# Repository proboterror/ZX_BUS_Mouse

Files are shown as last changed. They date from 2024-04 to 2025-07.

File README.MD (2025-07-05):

# ZX-BUS PS/2 Kempston Mouse Controller

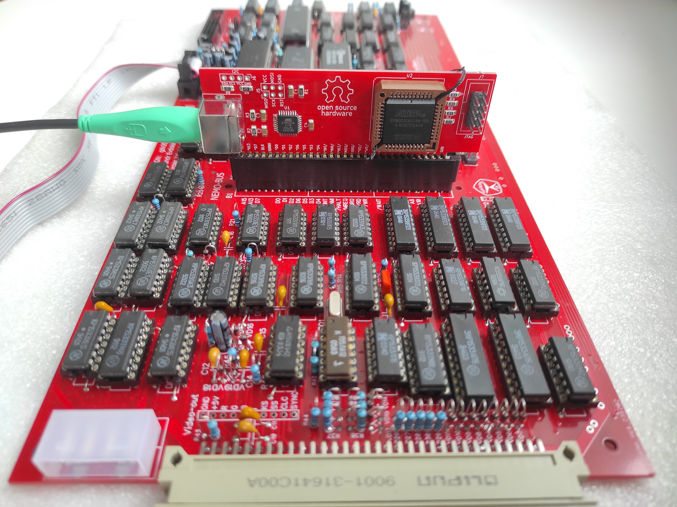
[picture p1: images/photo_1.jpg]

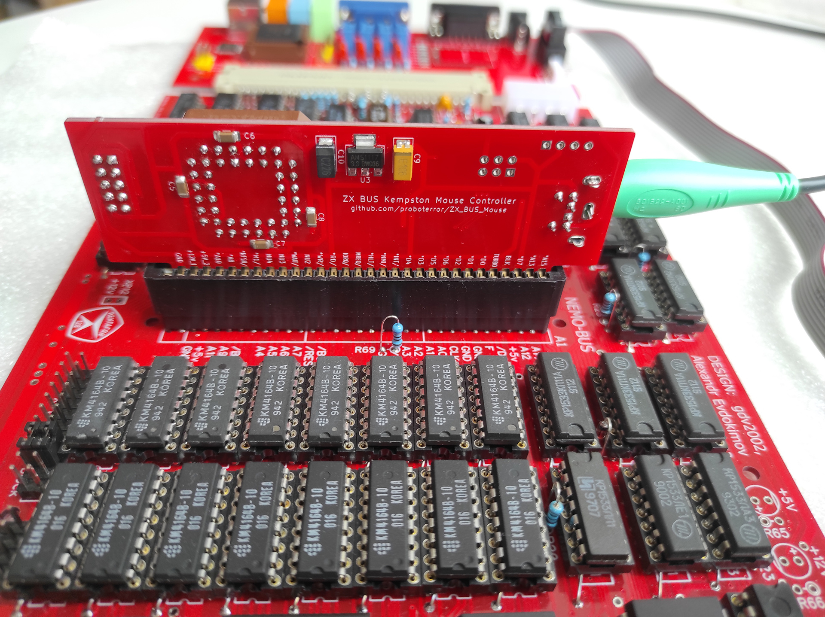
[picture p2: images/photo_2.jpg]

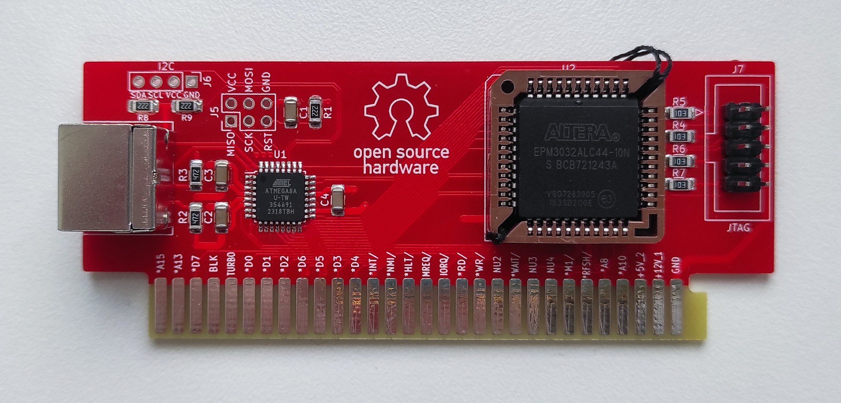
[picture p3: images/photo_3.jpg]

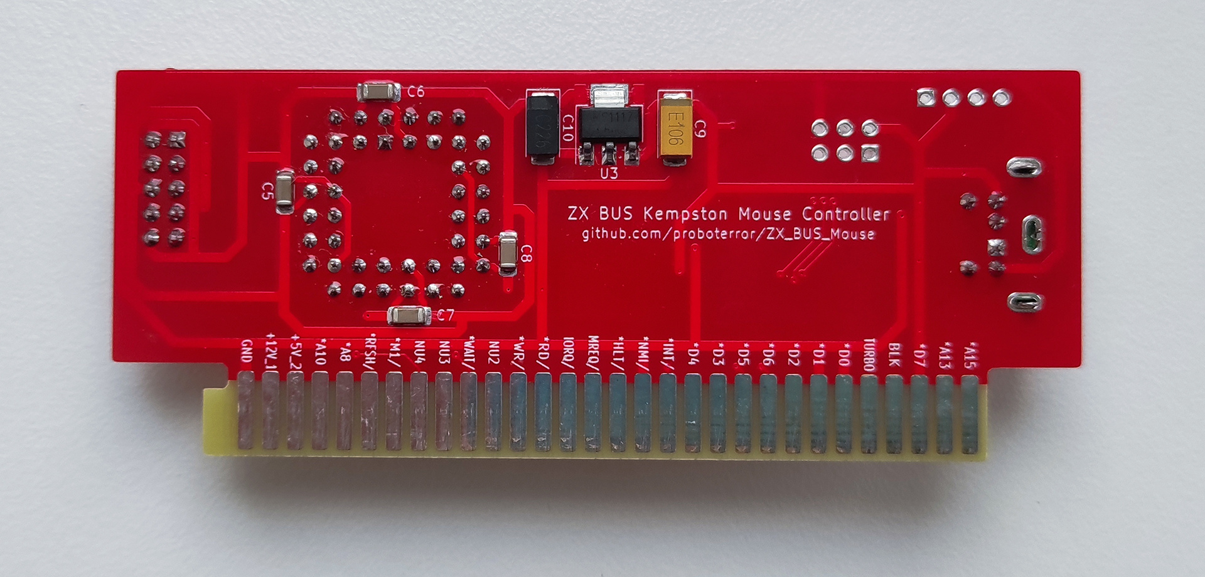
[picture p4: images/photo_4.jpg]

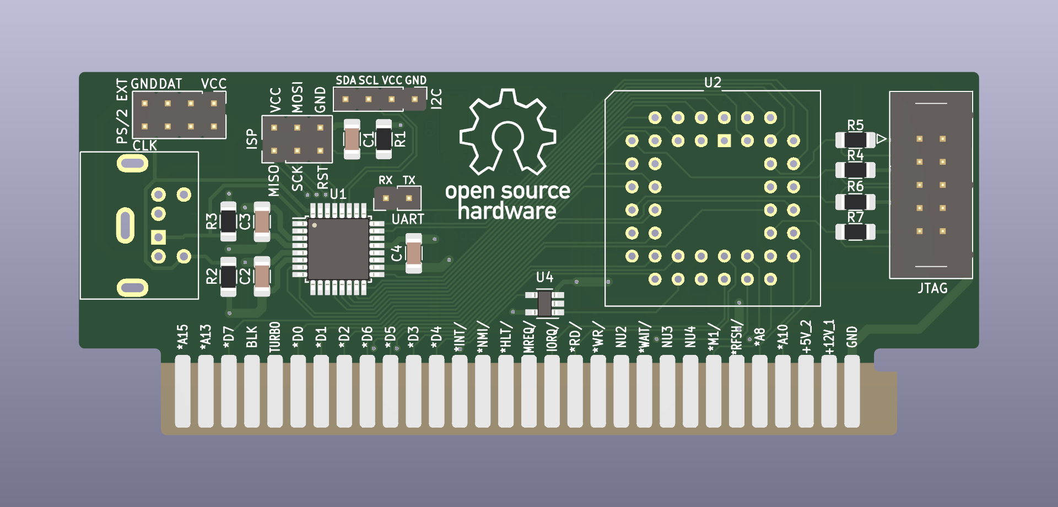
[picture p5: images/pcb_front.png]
pcb_front

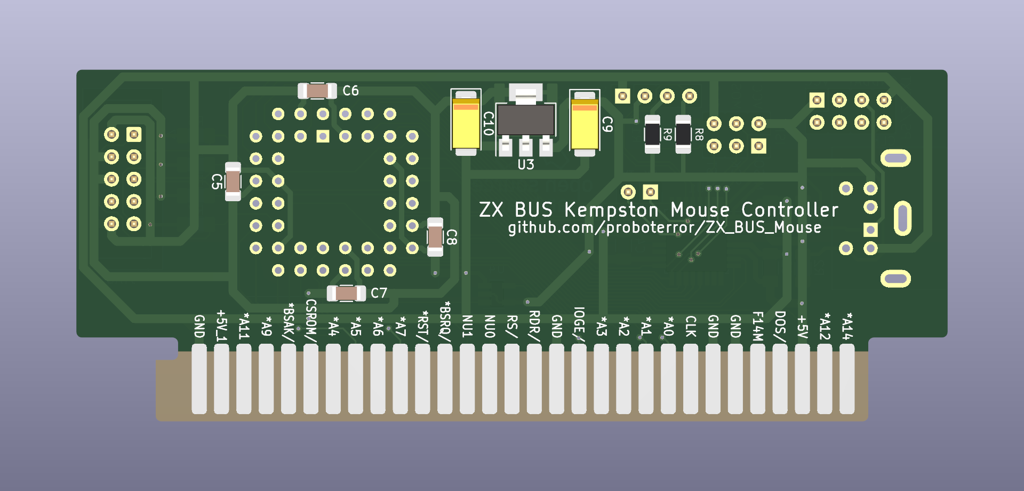
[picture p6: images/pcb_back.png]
pcb_back

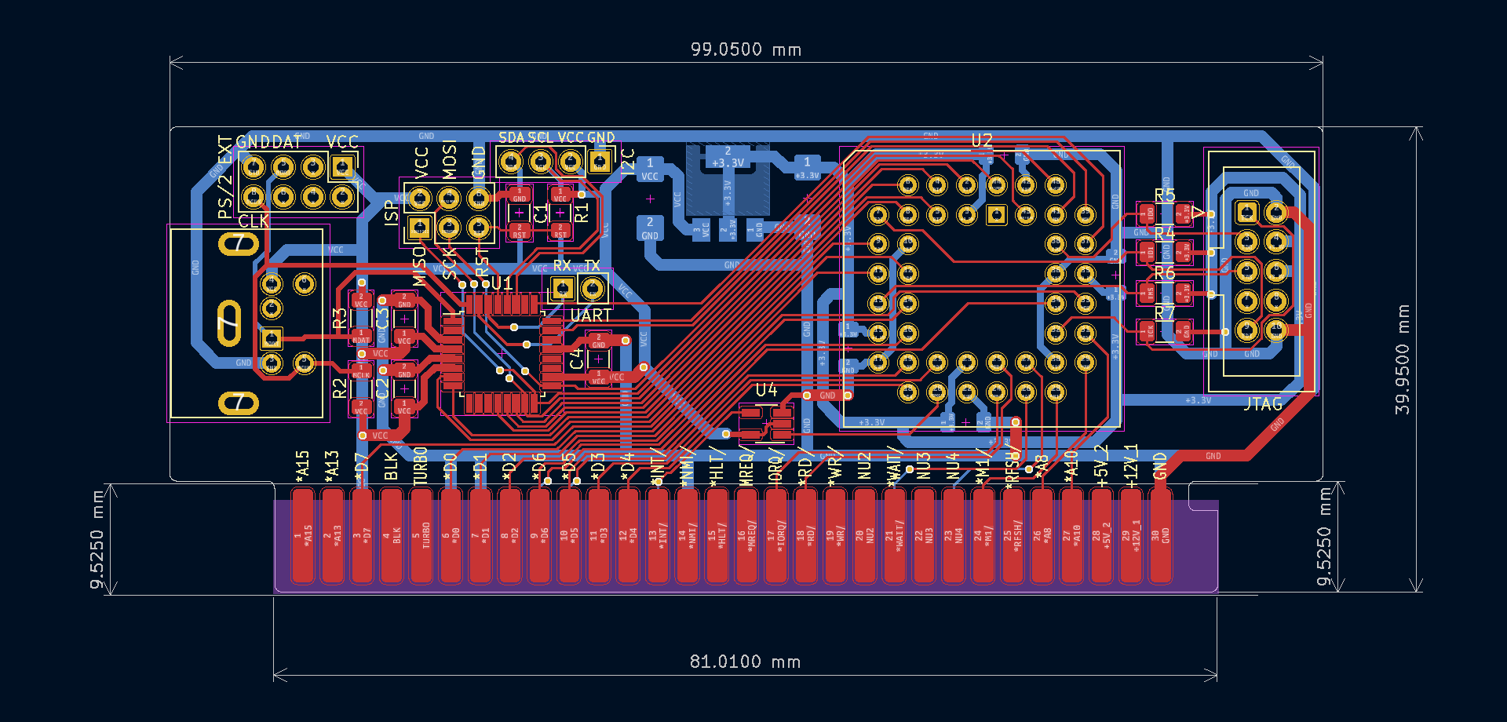
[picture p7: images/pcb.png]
pcb

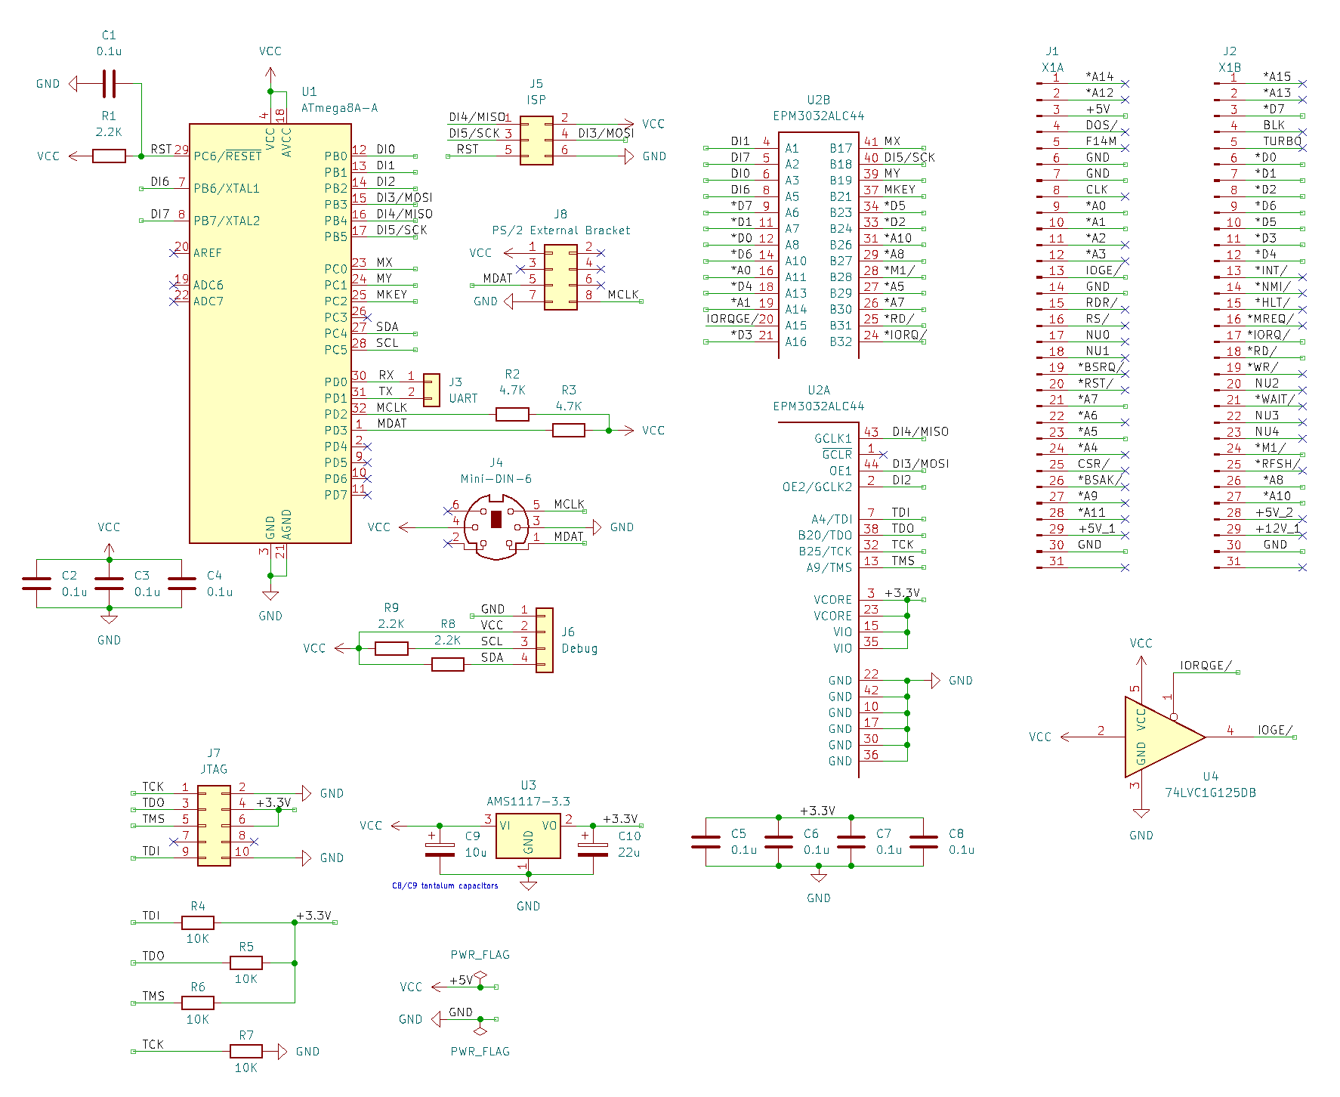
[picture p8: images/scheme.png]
scheme


## История версий
**V.1.0**
* Сигнал IORQGE/ имеет уровень 3.3V (LVTTL). Плата не работает корректно в ZX-BUS XTRaiser.
* Для включения поддержки колеса мыши нужна CPLD EPM3064.
* При включении регистры контроллера MX, MY, MKEY инициализируются некорректно в 0xFF, 0x80, 0x60: должно быть 0x80, 0x60, 0xFF (в регистре MKEY кнопки должны быть отжаты).

**V.1.1**
* Сигнал IORQGE/ буферизирован через 3-state buffer 74LVC1G125 до уровня TTL (5V) для исправления конфликта с ZX-BUS XTRaiser, общей стабильности и предупреждения обратного тока с других карт через IO выход CPLD. Решение подсмотрено в схемах в ZX-Multisound и ZXM-GeneralSound.
* Добавлен разъем для подключения внешнего брекета PS/2 (распространенная распиновка PC AT 486/Pentium материнских плат)
* Добавлен разъем UART для отладки
* Ширина краевого разъема ZX-BUS увеличена с 80 до 81 мм
* Описание схемы в CPLD переписано на Verilog и оптимизировано для поддержки колеса мыши на EPM3032 при отказе от третьей кнопки мыши (32 macrocells). Возможна сборка без поддержки колеса мыши (31 macrocells) и с полной поддержкой (34 macrocells).
* Не корректно работает с теневым монитором Scorpion (меню, не грузятся программы из ROM диска при активированной мыши). Нужен сигнал A15 в дешифрацию портов.

**V.1.2**
* Исправление загрузки с ROM диска в ПрофПЗУ Scorpion ZS 256. В дешифрацию портов и формирование сигнала IORQGE добавлен сигнал A15.

## Входные требования:
* Разработать максимально компактный простой в повторении интерфейс PS/2 Kempston Mouse для шины ZX BUS.
* Исходники прошивок микроконтролллеров / CPLD, схема и разводка платы должны быть полностью открыты.
* Сигнал WAIT микропроцессора не должен использоваться.

Не входит в требования:
* Поддержка USB мыши. Объем аппаратной и программной поддержки USB стека в микроконтроллере не соответствует сложности задачи.

## Описание интерфейса Kempston Mouse
Контроллер доступен как 3 8-разрядных регистра кнопок и осей X/Y MKEY, MX, MY по следующим адресам портов:
<pre>
#FADF 1111 1010 1101 1111 BUTTONS
#FBDF 1111 1011 1101 1111 MX
#FFDF 1111 1111 1101 1111 MY
</pre>

* Биты 0-2 регистра MKEY соответствуют инвертированным значениям левой, правой, средней кнопок мыши.<br>
* Бит 3 регистра MKEY зарезервирован под четвертую кнопку мыши и всегда равен 1.<br>
* Биты 4-7 регистра MKEY хранят значение оси mouse wheel, если она поддержана (начальное значение %0000). Если ось mouse wheel не поддержана, всегда содержат %1111.

При переполнении 8-bit значений координат осей происходит перенос значения. Фактически значения осей 8-бит целое со знаком в дополнительном коде.

Спецификация оси mouse wheel была публично зафиксирована в [сообщении в Fido эхоконференции REAL SPECCY](https://groups.google.com/g/fido7.real.speccy/c/Qeid4aFhjRg)

Дополнительная информация: [https://speccy.info/Kempston_Mouse](https://speccy.info/Kempston_Mouse)

## Некоторые исторические реализации и публикации
[Original Kempston Mouse Interface (1986)](https://k1.spdns.de/Vintage/Sinclair/82/Peripherals/Mouse%20Interfaces/Kempston%20Mouse%20Interface/)

[ZX-Ревю 1995 #1](history/zx-review_1995-01.txt)
[[схема]](history/zx-review_1995-01.png)<br>
KEMPSTON-MOUSE<br>
(С) М.Свечков (схема), К.Мехедов (программа) 1995

Фирма Scorpion & Д.К. (Санкт-Петербург 1995-97)<br>
[Контроллер IBM PC-клавиатуры и мыши](https://web.archive.org/web/20010308054936/http://scorpion.ru/spectrum/hard/kontroller_IBM.htm)<br>
[Схема](history/scorpion_keyboard_mouse_controller_scheme.png) [Прошивка V2.5](history/scorpion_keyboard_mouse_controller_2.5_firmware.zip)<br>
Инструкция по работе и подключению: V2.1: [1](history/scorpion_keyboard_mouse_controller_2.1_1.png) [2](history/scorpion_keyboard_mouse_controller_2.1_2.png) 
V2.5: [1](history/scorpion_keyboard_mouse_controller_2.5_1.jpg) [2](history/scorpion_keyboard_mouse_controller_2.5_2.jpg)<br>
Публикации:
[ZX Format #01 (31 октября 1995)](https://zxpress.ru/article.php?id=319)
[On-Line #15 (17 декабря 1995)](https://zxpress.ru/article.php?id=1989)
[On-Line #16 (24 декабря 1995)](https://zxpress.ru/article.php?id=1994)

[Схема от Михаила Кондратьева (17 апреля 1995)](history/kempmous.txt)

Интерфейс Kempston Mouse от Create Soft (Максим Романов, Mad Max & RML) (Санкт-Петербург)<br>
[ZX-Format #5 (12 декабря 1996)](https://zxdn.narod.ru/hardware/zf5kempm.htm)
[[screenshot]](history/zx-format_5.png)<br>
Схемa KEMPSTON MOUSE<br>
(С) Mad Max

[Spectrofon #20 (12 октября 1996)](https://zxpress.ru/article.php?id=4708)
[[text]](history/spectrofon_20.txt)
[[screenshot]](history/spectrofon_20.png)
[[схема]](history/spectrofon_20_kempston_mouse.png)<br>
ZX-SPECTRUM и МЫШЬ<br>
(C) Владимиp Лаpьков, 1996, Санкт-Петербург

AY Mouse<br>
[ZX Power #1 (12.10.1996)](https://zxdn.narod.ru/hardware/zpw1ayms.htm)<br>
В ЗАЩИТУ БЕДНОЙ МЫШКИ<br>
(C) V.M.G., Харьков

[Optron #13 (12 июня 1998)](https://zxdn.narod.ru/hardware/op13kemp.htm)
[[screenshot]](history/optron_13.png)<br>
Kempston mouse<br>
(C) Рашпиль, Сергей Филимонов

[ZX Club #09 (31 октября 1998)](https://zxpress.ru/article.php?id=14937)
[[screenshot]](history/zx-club_9.png)<br>
Kempston mouse<br>
(С) SERGIUS PUZZLER / PROXIMA

[Adventurer #11 (31 июля 2000)](https://zxdn.narod.ru/hardware/ad11kmse.htm)
[[screenshot]](history/adventurer_11.png)<br>
Описание на подключение Kempston MOUSE (простая и маленькая схема)<br>
(C) Паршуков XN0ByS Юрий/CPU

[Deja Vu #0A (30 сентября 2000)](https://zxdn.narod.ru/hardware/dv0akemp.htm)
[[text]](https://zxpress.ru/article.php?id=11221)
[[screenshot]](history/dejavu_0a.png)<br>
Схема Kempston Mouse Interface (v2.1) на БИС KP580BB55A<br>
(C) Felix Knajzev

Поддержка оси mouse wheel<br>
[DonNews #19 (26 февраля 2003)](https://zxpress.ru/article.php?id=6538)
[[screenshot]](history/donnews_19.png)<br>
KEMPSTON MOUSE INTERFACE<br>
(C) Bit/XXL

[Схема контроллера мыши на AT89C2051 (MSC-51)](history/kmsps2.txt)<br>
Опубликовано в ZX-Net эхоконференции HARDWARE.ZX (21 Aug 2000)<br>
(C) Eugene Stahov 1999-2000<br>
Микроконтроллер AT89C1051/AT89C2051, исходный код прошивки закрыт.<br>
Использует сигнал WAIT при опросе регистров интерфейса.

[PS/2 -> Kempston Mouse Adapter v2.0](history/atmelps2.txt)<br>
Опубликовано в Fido эхоконференции ZX.SPECTRUM (2003-01-10)<br>
(C) 1999-2000 Studio STALL (Eugene Stahov)<br>
(C) 2003 Kamil Karimov<br>
Микроконтроллер AT90S2313 (или AT90S1200), исходный код прошивки закрыт.<br>
Использует сигнал WAIT при опросе регистров интерфейса.

[PS/2 -> Kempston Mouse Adapter v4.0](history/zxkmv40.zip)
[[схема]](history/zxkm4.png)<br>
(C)2010 Kamil Karimov<br>
Не использует сигнал WAIT.<br>
Для обеспечения работы контроллера без торможения Z80 микроконтроллер ATTiny2313 работает на частоте 20 Мгц.<br>
Исходный код прошивки микроконтроллера закрыт.

The Kempston Mouse Turbo Interface [2006/2008](https://velesoft.speccy.cz/kmturbo-cz.htm)/[2011](https://velesoft.speccy.cz/kmouse/km-doc/kempston_mouse_turbo_interface/km-t_2011/k-mouse2011-doc.pdf) by Velesoft and Ben Versteeg<br>
[PC Mouse and Kempston joystick Interface for the Sinclair ZX Spectrum](https://www.benophetinternet.nl/hobby/kmt/)<br>
Поддержка master/slave mouse, mouse wheel.<br>
Микроконтроллер PIC16F84A + CPLD XC9572X<br>
Исходный код прошивки микроконтроллера закрыт.

[Z-Controller](http://pentagon.nedopc.com/info.htm)<br>
(C) Алексей Жабин KingOfEvil 2007<br>
Позволяет подключать к ZX Spectrum стандартную клавиатуру и мышь с интерфейсом PS/2, IDE-устройства, карты флеш-памяти стандарта SD. Устройство предназначено для установки в слот ZX Bus.<br>
[Документация](http://svn.zxevo.ru/filedetails.php?repname=pentevo&path=/docs/ZC.pdf)<br>
Микроконтроллер КР1878ВЕ1 + CPLD EPM7128SLC84<br>
[Исходный код прошивок CPLD и микроконтроллера открыт в 2024 году](https://github.com/koe1234/Z-controller)

[ZX Evolution](http://www.nedopc.com/zxevo/zxevo.php)<br>
(C) NedoPC 2010<br>
Периферийный контроллер ATMEGA128<br>
PS/2 интерфейс клавиатуры и мыши<br>
[Open source](http://svn.zxevo.ru/listing.php?repname=pentevo)

[ZX_Multi_Card ZXMC1/ZXMC2](https://zx-pk.ru/threads/609-zx_multi_card.html)<br>
(C) caro Kamil Karimov 2005<br>
Поддерживает:<br>
- IBM AT клавиатуру - эмулирует стандартную клавиатуру Спектрума;<br>
- PS/2 мышка - эмулирует Кемпстон мышку (с колесом);<br>
- RS232 - поддержка внешнего модема с адресацией по Кондратьеву.<br>
- Часы реального времени (RTC)

Closed source

[Схема контроллера Kempston Mouse для Nemo-BUS](https://zxbyte.ru/kempston_mouse_for_zx.htm) (модификация схемы из Spectrofon #20)<br>
(C) Prusak 2016

[Контроллер для USB клавиатуры и мыши](https://zx-pk.ru/threads/34912-kontroller-dlya-usb-klaviatury-i-myshi.html)
[[github]](https://github.com/Igor-azx987sa/ZXKM)<br>
(С) Игорь Матвеев @azx987sa 2023<br>
Микроконтроллер CH9350<br>
Closed source

## Детали реализации:
Для реализации была выбрана связка ATmega8 + EPM3032.<br>
Общая идея контроллера Kempston Mouse на ATmega+EPM3032, [схема включения и выбор битов адреса для дешифрации портов](images/deltagon_1.5_mouse_controller.png) были взяты из [Deltagon 1.5](https://t.me/Pentagon_ZX_Chat/126403) (C) Евгений Королёв @djking26, Игорь Матвеев @azx987sa.

Прошивка ATmega для обработки протокола написана на языке C. В отдельной ветке есть упрощенная прошивка на библиотеках Arduino.<br>
Аппаратные прерывания ATmega по фронтам сигналов PS/2 MDATA/MCLK и таймеры не использовались для большей понятности кода. Тем не менее, сигналы MDATA/MCLK подключены к входам INT1/INT0 микроконтроллера, есть [альтернативная прошивка](https://github.com/proboterror/ZX_BUS_Mouse/tree/interrupt_processing), использующая аппаратное прерывание от сигнала PS/2 clock. Альтернативная прошивка предназначена в первую очередь для разработчиков.

Реализация регистров интерфейса, схемы дешифрации адресов и формирования сигнала IORQGE для CPLD EPM3032 выполнена на языке Verilog. Также есть признанная менее понятной реализация на VHDL.

Текущая реализация использует 31 из 32 macrocells в CPLD EPM3032 c отключенными битами оси mouse wheel в регистре кнопок мыши, 33 macrocells при включении битов оси mouse wheel.<br>
Теретически возможно использование менее доступной и более дорогой CPLD EPM3064 или оптимизация модели в Verilog и распределения ресурсов в CPLD.<br>
По умолчанию включена поддержка двух кнопок и mouse wheel, используется 32 macrocells.

При подаче питания на контроллер до прихода первого пакета событий от PS/2 мыши в регистры MKEY, MX, MY всегда записываются значения 0xFF, 0x80, 0x60.<br>
При отключенной поддержке оси mouse wheel в старших 4 битах регистра MKEY %1111, при включенной поддержке начальное значение оси %0000.

Формирование сигнала IORQGE/ происходит исходя из общих битов адресов портов A0,A1,A7,A5/ и сигнала M1/.

Отладка устройства проводилась на [Pentagon 2024](https://t.me/Pentagon_ZX_Chat/125656) и сверялась с эмулятором Unreal Speccy 0.39.0, выбранным как референс реализации.
Подтверждена работа на Scorpion ZS 256, Scorpion ZS 1024, Pentagon 1024ZP Crocodile Edition.

Условная эквивалентная схема контролллера в CPLD:
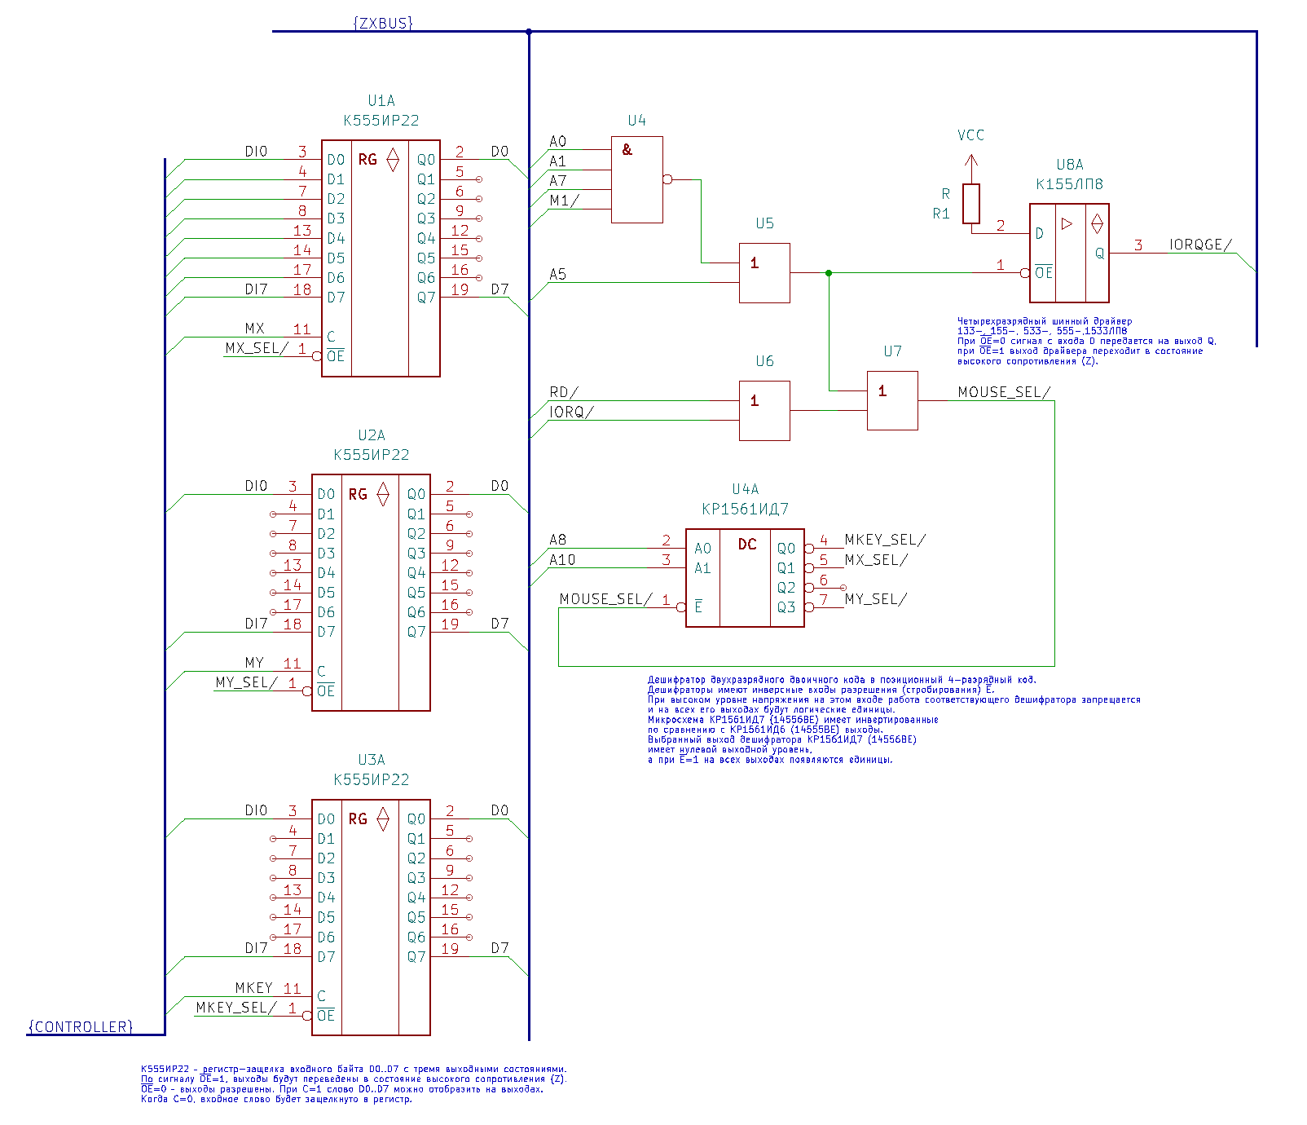
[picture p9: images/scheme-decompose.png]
scheme-decompose


## Известные проблемы:
На Scorpion ZS 256 в меню сервисного монитора мышь работает некорректно, при этом тест, загруженный в RAM, работает корректно.
Не работает загрузка с ROM диска в ПрофПЗУ при включенной опции графических манипуляторов.
Симптоматически исправилось включением сигнала A15 в схему дешифрации, аргументированного объяснения этому пока нет. Также проблема исправляется использованием сигнала /DOS.

Была замечена некорректная работа регистров осей в CPLD: выглядело как перепутанная пара битов. Решилось перекомпиляцией описания схемы и прошивкой CPLD.

На некоторых платах с неправильной реализацией IORQGE теоретически возможен конфликт с портом Kempston Joystick.

## Сомнительно:
PS/2 мышь может требовать задержку перед инициализацией после подачи питания. Решено перезагрузкой контроллера после 2 секунд ожидания инициализации устройства PS/2.

Gluk Reset Service проверяет наличие мыши сразу после включения (24 ms для Pentagon 2024: 10K+10uF в цепи сброса Z80: длительность RESET 10 ms).<br>
Проверки:<br>
- В цикле неясной длительности проверяется, что значение оси X не меняется
- Проверяется, что регистр KEY не равен регистру X
- Проверяется, что младшие 3 бита регистра KEY равны 1

Проблема:<br>
Мышь при включении автоматически не определяется, но определяется после сброса. Можно принудительно включить мышь через клавишу [8].<br>
Суть проблемы в том, что микроконтроллер ATmega не успевает проинициализировать PS/2 мышь (1-2 s) и выставить значения регистров контроллера по умолчанию (~6 us).<br>

Варианты решения:<br>
- Для определения наличия подсоединенной к контроллеру мыши требуется до 1-2 секунд, в течении которых сигнал /RESET Z80 удерживается контроллером, как это например сделано в контроллере ZXMC.
- Инициализировать регистры контроллера сразу после включения, не дожидаясь проверки наличия PS/2 мыши. Все еще может требовать внешней задержки старта Z80. Для ПО подобного Gluk тест наличия мыши будет проходить, даже если PS/2 мышь не присоединена.

В коде реализован второй вариант.

## Bill of materials
|Ref|Qnty|Value|Cmp name|Footprint|Description|
|-----|-----|-----|-----|-----|-----|
|C1, C2, C3, C4, C5, C6, C7, C8|8|0.1u|C|Capacitor_SMD:C_1206_3216Metric|Unpolarized capacitor|
|C9|1|10u|C_Polarized|Capacitor_Tantalum_SMD:CP_EIA-6032-28_Kemet-C_Pad2.25x2.35mm|Polarized capacitor|
|C10|1|22u|C_Polarized|Capacitor_Tantalum_SMD:CP_EIA-6032-28_Kemet-C_Pad2.25x2.35mm|Polarized capacitor|
|J4|1|Mini-DIN-6|Mini-DIN-6|Connector_Mini-DIN_Female_6Pin_2rows|6-pin Mini-DIN connector|
|J5|1|Conn_02x03_Odd_Even ISP|Conn_02x03_Odd_Even|Connector_PinHeader_2x03_P2.54mm_Vertical||
|J7|1|Conn_02x05_Odd_Even JTAG|Conn_02x05_Odd_Even|Connector_IDC-Header_2x05_P2.54mm_Vertical||
|R1|1|2.2K|R|Resistor_SMD:R_1206_3216Metric|Resistor|
|R2, R3|2|4.7K|R|Resistor_SMD:R_1206_3216Metric|Resistor|
|R4, R5, R6, R7|4|10K|R|Resistor_SMD:R_1206_3216Metric|Resistor|
|U1|1|ATmega8A-U|ATmega8A-U|Package_QFP:TQFP-32_7x7mm_P0.8mm|16MHz, 8kB Flash, 1kB SRAM, 512B EEPROM, TQFP-32|
|U2|1|EPM3032ALC44|EPM3032ALC44|Package_LCC:PLCC-44_THT-Socket|CPLD MAX3000A MCs:32 IOs:34 [PLCC-44]|
|U3|1|AMS1117-3.3|AMS1117-3.3|Package_TO_SOT_SMD:SOT-223-3_TabPin2|1A Low Dropout regulator, positive, 3.3V fixed output, SOT-223|
|U4|1|74LVC1G125DB|74LVC1G125|Package_TO_SOT_SMD:SOT-23-5|Single Buffer Gate Tri-State, Low-Voltage CMOS|

IC Socket PLCC-44 THT DIP

Разъем J4 PS/2 зеленый с прямыми ушками.<br>
Разъемы программаторов J5, J7 - любой pin header 2x03, 2x05 2.54mm. Запаивать их не обязательно.<br>
Конденсаторы C9, C10 линейного преобразователя напряжения танталовые согласно [datasheet](http://www.advanced-monolithic.com/pdf/ds1117.pdf).

Отладочные компоненты:
|Ref|Qnty|Value|Cmp name|Footprint|Description|
|-----|-----|-----|-----|-----|-----|
|R8, R9|2|2.2K|R|Resistor_SMD:R_1206_3216Metric|Resistor|
|J6|1|Conn_01x04 Debug|Conn_01x04|Connector_PinHeader_1x04_P2.54mm_Vertical||

## Сборка прошивок

### ATmega8
Нужно установить AVR SDK: WinAVR-20100110<br>
Также для GNU утилит может потребоваться установить [MSYS2](https://www.msys2.org/). Путь к msys64/usr/bin должен быть в PATH.<br>

Compile:
<pre>
make clean
make all
</pre>

[Собранная прошивка](source/ATmega/main.hex) с включенной поддержкой mouse wheel и отключенным отладочным выводом на OLED дисплей.

### Altera EPM3032
Для сборки и заливки прошивки CPLD необходима бесплатная версия ПО Quartus II Web Edition версии 9.1 SP2 / 13.0 SP1<br>
Последовательность компиляции и прошивки:<br>
- File/Open Project<br>
- Processing/Start Compilation<br>
- Tools/Programmer<br>
- При необходимости выбрать программатор USB Blaster через Hardware Setup<br>
- Для файла скомпилированной прошивки mouse_controller.pof выбрать Program/Configure и Verify.<br>
- Start.

## Заливка прошивки

### ATmega8
Для прошивки ATmega можно использовать программатор CH341A и ПО NeoProgrammer V2.2.<br>
Последовательность прошивки:<br>
- Убедиться, что микроконтроллер доступен и определяется через SPI: Нажать Detect.<br>
- Если контроллер не определяется, то возможна ошибка соединения проводов с программатором, отсутствие контакта в разъеме ISP, ошибки сборки, в микроконтроллере могут быть прошиты fuses для использования внешнего кварцевого резонатора.<br>
- Выставить Fuses через соответствующий диалог, нажать Write.

[Fuses для прошивки ATmega8:](source/ATmega/fuses.png)
<pre>
Low     High
0xC4    0xD9
</pre>

- Открыть файл .hex прошивки через Open File.<br>
- Через Write IC сделать Erase/Write/Verify.

При некоторой сноровке гребенки разъемов ISP и JTAG можно не припаивать, а прижать под углом на время прошивки.

### Altera EPM3032
Для прошивки по JTAG может быть использован дешевый аналог Altera USB Blaster.<br>
Несколько более дорогие аналоги USB Blaster на FT245+CPLD возможно более совместимы  в установке и работе (не проверялось).

Доступные дешевые аналоги Altera USB Blaster Rev.c на CH552G условно работоспособны, нужно обновление прошивки программатора.<br>
Требуется WCHISPTool и прошивка [CH552_Blaster_v22.2.27.hex](https://github.com/xjtuecho/CH552Nano/blob/main/FW/CH552_Blaster_v22.2.27.hex)<br>
Подробнее: [Прошивка китайского USB-Blaster на основе CH552G](https://ua3reo.ru/proshivka-kitajskogo-usb-blaster-na-osnove-ch552g/)<br>
Драйвер программатора устанавливается из папки установки quartus/drivers/usb-blaster

После запайки в плату всех компонентов помимо CPLD и обвязки JTAG, в первую очередь преобразователя питания 5V=>3.3V, при подаче питания 3.3V на разъем JTAG с программатора напряжение питания падает до ~2V.<br>
CPLD определяется в Quartus, но не прошивается.<br>
Нужно подать на плату внешнее питание 5V через разъем ISP или слот ZX-BUS.<br>
На практике при отладке плата успешно перешивалась на лету на включенном Pentagon 2024.<br>
Требуется особая осторожность при подключении программаторов через USB, необходимо выполнять на выключенном устройстве.

Бывшие в употреблении чипы EPM3032 могут быть залочены и не видны через JTAG интерфейс. Можно [попытать удачи в процедуре unlock](https://zx-pk.ru/threads/25998-programmator-mikroskhem-programmiruemoj-logiki(cpld).html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), или заказать у другого поставщика.

### Поддержка mouse wheel
Поддержка mouse wheel в регистре кнопок контроллера включена по умолчанию с отключенной третьей кнопкой мыши. Эта реализация использует 32 macrocells и помещается в EPM3032 (source/Altera-VHDL/mouse_controller.v):
```
	// Example 2 buttons mouse support with mouse wheel (32 macrocells)
	// Exclude 3rd mouse button and reserved bit from output in order to fit to EPM3032.
	assign D = MKEY_SEL ? {register_key[7:4], 2'b11, register_key[1:0]} : 8'hZ;
```
Для поддержки третьей кнопки мыши без колеса прокрутки заменить на:
```
	// Example 3 buttons mouse support with mouse wheel turned off (31 macrocells)
	assign D = MKEY_SEL ? {4'b1111, register_key[3:0]} : 8'hZ;
```
Для полной поддержки заменить на:
```
	// Example 3 buttons mouse support with mouse wheel (34 macrocells)
	assign D = MKEY_SEL ? register_key : 8'hZ;
```
Целевым устройством указать EPM3064.

Работа с EPM3064 подтверждена.

## Отладка
ПО для тестирования интерфейса: [MousTest (C) 2012 Patrik Rak - Raxoft](test/Test%20Mouse.trd.zip)

Для отладки интерфейса PS/2 можно использовать OLED I2C Display 128x32. Должны быть запаяны резисторы подтяжки I2C SDA/SCL R8, R9.<br>
Припаивать дисплей не нужно, достаточно контакта в разъеме I2C под собственным весом дисплея.<br>
В Makefile нужно включить отладочный код и пересобрать с библиотекой [OLED for AVR mikrocontrollers](https://github.com/Sylaina/oled-display):
```c
CFLAGS += -DDEBUG=1
```
Можно отследить шаги инициализации устройства PS/2, тип устройства, обработку осей, кнопок и колеса мыши.

Проверка инициализации и работы PS/2 мыши микроконтроллером ATmega8:<br>
Вариант 1:<br>
- Вставить OLED дисплей 128x132 в разъем I2C.
- Прошить отладочную прошивку [ZX_BUS_Mouse_ATmega8_Fuses_C4_D9_Debug_OLED_128x32.hex](source/ATmega/Debug/ZX_BUS_Mouse_ATmega8_Fuses_C4_D9_Debug_OLED_128x32.hex)

При включении выводится надписи Init... Done и далее при движении мыши ее координаты и состояние оси wheel / кнопок.

Вариант 2:<br>
- Присоединить светодиод к контактам разъема I2C GND и SDA. Короткий пин светодиода к GND.
- Прошить отладочную прошивку [ZX_BUS_Mouse_ATmega8_Fuses_C4_D9_Debug_LED_SDA_GND.hex](source/ATmega/Debug/ZX_BUS_Mouse_ATmega8_Fuses_C4_D9_Debug_LED_SDA_GND.hex)

При включении после успешной инициализации PS/2 мыши светодиод загорается. При нажатии кнопок гаснет.

## Credits
* Общая идея контроллера Kempston Mouse на связке ATmega+EPM3032, схема включения и выбор битов адреса для дешифрации портов: [Deltagon 1.5](https://t.me/Pentagon_ZX_Chat/126403) (C) Евгений Королёв @djking26, Игорь Матвеев @azx987sa 
* @Alex_Eburg - [ZX BUS PCB Prototype Board](https://github.com/AlexEkb4ever/ZX_BUS)
* Black_Cat - [BC Info Guide #7. Стандартизация ZXBus интерфейсов и шин.](https://zx.clan.su/forum/7-82-1) (c) Black_Cat 2011-2020
* Adam Chapweske - PS/2 Mouse/Keyboard Protocol (C) 1999, The PS/2 Mouse Interface (C) 2003
* Kris Chambers - [Arduino/Wiring Library for interfacing with a PS2 mouse](https://github.com/kristopher/PS2-Mouse-Arduino)
* [Patrik Rak raxoft](https://github.com/raxoft) - MousTest
* Sylaina - [OLED for AVR mikrocontrollers](https://github.com/Sylaina/oled-display) library
* Velesoft - [RUSKA VERZE KEMPSTON MOUSE](https://velesoft.speccy.cz/kmrus-cz.htm) - скриншоты статей из электронных журналов
* Zxdn - [Электроника/схемы устройств - Клавиатуры, мыши](https://zxdn.narod.ru/hardware.htm#inputdev)
* Калинин Вячеслав/newart - [zxpress.ru](https://zxpress.ru)
* @AMM - поддержка в начальном запуске
* @Michael_Kaa - помощь в тестировании на Scorpion ZS 256
* Denis (Новый Уренгой) - тестирование и отладка на Scorpion ZS 256
* @djking26 - локализация проблемы с Gluk Reset Service

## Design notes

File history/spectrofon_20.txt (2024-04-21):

Spectrofon #20
11 октября 1996
  Железо  
Конструктор - ZX Spectrum и Мышь (схема, программирование и драйвер).

   Hадо сказать, к нам в  pедакцию  пpихо-
дит много статей пpо  подключение  мыши  к
Спектpуму. Однако, публикуемая статья,  на
наш взгляд, является лучшей на эту тему.

(c) Владимиp Лаpьков, 1996. С.-Петеpбуpг.

          ZX-SPECTRUM и МЫШЬ
     ════════════════════════════

   Hа тему подключения мышки  к  Спектpуму
уже не pаз говоpилось на стpаницах компью-
теpной пpессы. Это были статьи  pекламного
хаpактеpа от  Питеpских  пpоизводителей  и
пpодавцов мышиных интеpфейсов. Я  не  буду
споpить ни с одним из них, я  пpосто  хочу
пpедложить  умеющим  деpжать    в    pуках
паяльник собpать данное устpойство  самос-
тоятельно.

   Для начала нужно  ответить  на  вопpос:
почему именно  Kempston  Mouse  Interface?
Ведь некотоpые умельцы умудpяются  пpипаи-
вать мышку  к  гнезду  Кемпстон-джойстика,
иные используют AY-mouse. Чем же  Kempston
Mouse Interface лучше?

   Пpежде всего надо заметить,  что  любые
попытки подсоединения мыши в гнездо  джой-
стика являются издевательством над  мышью.
Мышь отличает одно замечательное  качество
- помимо напpавления пеpемещения она  pеа-
гиpует  также  на  скоpость  этого  самого
пеpемещения, поэтому куpсоp на экpане дви-
жется пpопоpционально движению вашей pуки,
т.е.  когда  вы  двигаете  мышь  медленно,
куpсоp движется также медленно,  когда  вы
двигаете мышь быстpо, куpсоp движется быс-
тpо. За счет этого pаботать мышью  несpав-
ненно удобнее, чем джойстиком. Джойстик же
не способен pеагиpовать на скоpость  пеpе-
мещения, он учитывает только  напpавление.
Поэтому, в случае подключения мыши в гнез-
до джойстика, вне зависимости от  того,  с
какой  скоpостью  вы  пеpемещаете    мышь,
куpсоp  будет  двигаться   с    постоянной
скоpостью. И на пеpемещение куpсоpа от од-
ного кpая экpана до дpугого вам  может  не
хватить площади стола. Cудя по всему, это-
го недостатка лишен ваpиант  AY-mouse.  Hо
под   AY-mouse    адаптиpовано    маловато
пpогpамм.

   Так почему  же  мы  так  усиленно  аги-
тиpуем вас за  Kempston  Mouse  Interface?
Ответ банален: дело в  стандаpтности.  Это
устpойство пpидумано достаточно давно, оно
является таким же стандаpтом, как Kempston
Joystick или Sinclair Joystick и его  под-
деpживают фиpменные пpогpаммы,  такие  как
напpимеp Art Studio или Artist II. Так за-
чем же выдумывать велосипед и плодить мас-
су своих стандаpтов, если пpоще  и  логич-
нее использовать то,  что  уже  пpидумано,
тем более, что под этот ваpиант уже сущес-
твует пpогpаммная поддеpжка.

   Самое большое pаспpостpанение  Kempston
Mouse Interface получил в  Питеpе,  это  и
понятно, ведь именно в Питеpе  был  сделан
его pусский аналог. Hаpяду с уже названны-
ми Art Studio и Artist II  фиpменную  под-
деpжку  Kempston  Mouse  удалось  найти  в
Victory  Road,  Battle  Command,   Carrier
Command.

   Очень  быстpо  были   адаптиpованы    к
Kempston    Mouse    Interface   пpогpаммы
F Commander v4.01, Instrument  v2.01,  DCU
2.32, etc...

   Hовые пpогpаммы стали писать  с  учетом
факта появления  на  свет  Kempston  Mouse
Interface и поддеpжку  мышки  можно  также
встpетить  в  FUT  v2.01,  ZXWORD   v2.5m,
ZxZip/ZxUnzip v1.02, Instrument v3.01, FPM
v3.5, и дpугих.

   Адаптиpовали   под    Kempston    Mouse
Interface и игpы,  напpимеp:  Hero  Quest,
Dragon Spirit, Space Crusade, A New  Whole
Ball Game, The A Team  1  &  2,  Operation
Wolf,  Operation  Thunderbolt,  World  Cup
Challenge, Gunsmoke, R-Type, Gemini  Wing,
1943 The Battle  Begin,  Zombi,  Armagedon
Man, etc...

   Hовый электpонный  жуpнал  ZX-Format  с
самого   пеpвого    номеpа    поддеpживает
Kempston  Mouse  Interface.  Пpочувствовав
пожелания знакомых, Слава Медноногов вста-
вил поддеpжку мышки в свою новую игpу  UFO
II, а попpобовав поигpать в нее мышью  ос-
тался очень доволен.

   К чему я веду pечь вpоде понятно. Коли-
чество мышиных пpогpамм неуклонно увеличи-
вается, пpактически  все  новые  Питеpские
автоpские пpогpаммы имеют поддеpжку мышки.
Фиpменные пpогpаммы, в котоpых  упpавление
мышью было бы логичным, также  адаптиpуют-
ся под Kempston Mouse Interface.

Какие еще нужны аpгументы именно  за  этот
девайс? Вpоде  бы  аpгументов  достаточно.
Пpосто попpобуйте pазок посидеть  в  мыши-
ной Аpт Студии, после этого  вас  вpяд  ли
затащишь обpатно. Вы будете беситься, гля-
дя на то,  как  долго  ползает  стpелочка,
упpавляемая джойстиком или кнопками. В  то
вpемя, как с мышью все пpосто  поpхает.  И
вы будете поpажены, поняв, сколько  вpеме-
ни вы тpатили на  пpостое  пеpемещение  по
менюшкам.

   Итак,   пpактически    все    Питеpские
пpогpаммисты    поддеpживают      стандаpт
Kempston Mouse Interface. Поэтому мы  пpи-
зываем всех юзеpов спаять себе данный  де-
вайс, а всех пpогpаммистов -  поддеpживать
именно его, чтобы  юзеpам  не  пpиходилось
слишком часто гpеть паяльник  пpи  появле-
нии  чего-нибудь  типа  Sinclair  Joystick
Mouse или скажем ZX Lprint III Mouse...

   Hа этом  вступительная  часть  заканчи-
вается, пеpеходим непосpедственно к схеме.

Автоpом схемы является Михаил  Кондpатьев,
схема  была  pазpаботана  после   изучения
дpайвеpов пpогpамм Art  Studio  и  Artist.
Пеpвоначальный ваpиант содеpжал 11  коpпу-
сов, это было связано с тем, что автоp ис-
пользовал наиболее доступные микpосхемы из
тех, что были под pукой. В дальнейшем  ко-
личество  микpосхем  было  сокpащено    до
восьми.  Hекотоpое  вpемя  схема  являлась
коммеpческим пpодуктом, пpава не нее  были
пеpеданы Сеpгею  Зонову.  В  пpошлом  году
Сеpгей Зонов pазpешил ее  pаспpостpанение,
после чего схема Kempston Mouse  Interface
была  обнаpодована  в  электpонной    сети
FidoNet.

   В  качестве  самого  манипулятоpа  чаще
всего используется обыкновенная сеpая пас-
сивная мышь от Поиска. Пpи минимальной це-
не она pаботает  достаточно  хоpошо.  Хотя
желающие могут  использовать  и  фиpменные
пассивные мыши.

   Пpи полном отсутствии в зоне  видимости
пассивных мышей можно использовать  и  ак-
тивные, пpавда, пpидется в них немного по-
ковыpяться (см. пpимечания к схеме).

     Схема Kempston Mouse Interface:

            DD1              DD5
        5┌──┬──┬─┐ 6     2┌──┬──┬─┐18 D0║
    ┌────oCa│CT│0├────────┤D1│|>│1├─────╢
Xb ─┴─ 15├──┤  │ │11     4│  │  │ │16 D1║
──┬──────/C │  │1├────────┤D2│  │2├─────╢
Xa│    10│  │  │ │14     6│  │  │ │14 D2║
───┬─────┤U/D  │2├────────┤D3│  │3├─────╢
  ││    9├──┤  │ │ 2     8│  │  │ │12 D3║
  ││ ┌───┤R │  │3├────────┤D4│  │4├─────╢
  ││ │  1│  │  │ │      11│  │  │ │ 9 D4║
  ││ ├───┤S │  │ │  ┌─────┤D5│  │5├─────╢
  ││─┴─ 4│  │  │ │  │   13│  │  │ │ 7 D5║
  ││   ──┤0 │  │ │  │┌────┤D6│  │6├─────╢
  ││   12│  │  │ │  ││  15│  │  │ │ 5 D6║
  ││   ──┤1 │  │ │  ││┌───┤D7│  │7├─────╢
  ││   13│  │  │ │  │││ 17│  │  │ │ 3 D7║
  ││   ──┤2 │  │ │  │││┌──┤D8│  │8├─────╢
  ││    3│  │  ├─┤ 7││││19├──┤  │ │     ║
  ││   ──┤3 │  │Co─┐││││┌─oE2│  │ │     ║
  ││     └──┴──┴─┘ ││││││1│  │  │ │     ║
  ││  ┌────────────┘││││├─oE1│  │ │     ║
  ││  │     DD2     │││││ └──┴──┴─┘     ║
  ││  │ 5┌──┬──┬─┐ 6│││││ /XCS          ║
  ││  └──oCa│CT│0├──┘│││└────           ║
  ││   15├──┤  │ │11 │││                ║
  └──────/C │  │1├───┘││                ║
   │   10│  │  │ │14  ││                ║
   └─────┤U/D  │2├────┘│                ║
        9├──┤  │ │ 2   │                ║
     ┌───┤R │  │3├─────┘                ║
     │  1│  │  │ │                      ║
     ├───┤S │  │ │                      ║
    ─┴─ 4│  │  │ │                      ║
       ──┤0 │  │ │                      ║
       12│  │  │ │                      ║
       ──┤1 │  │ │                      ║
       13│  │  │ │                      ║
       ──┤2 │  │ │                      ║
        3│  │  ├─┤ 7                    ║
       ──┤3 │  │Co──                    ║
         └──┴──┴─┘                      ║
            DD3              DD6        ║
        5┌──┬──┬─┐ 6     2┌──┬──┬─┐18 D0║
    ┌────oCa│CT│0├────────┤D1│|>│1├─────╢
Ya ─┴─ 15├──┤  │ │11     4│  │  │ │16 D1║
──┬──────/C │  │1├────────┤D2│  │2├─────╢
Yb│    10│  │  │ │14     6│  │  │ │14 D2║
───┬─────┤U/D  │2├────────┤D3│  │3├─────╢
  ││    9├──┤  │ │ 2     8│  │  │ │12 D3║
  ││ ┌───┤R │  │3├────────┤D4│  │4├─────╢
  ││ │  1│  │  │ │      11│  │  │ │ 9 D4║
  ││ ├───┤S │  │ │  ┌─────┤D5│  │5├─────╢
  ││─┴─ 4│  │  │ │  │   13│  │  │ │ 7 D5║
  ││   ──┤0 │  │ │  │┌────┤D6│  │6├─────╢
  ││   12│  │  │ │  ││  15│  │  │ │ 5 D6║
  ││   ──┤1 │  │ │  ││┌───┤D7│  │7├─────╢
  ││   13│  │  │ │  │││ 17│  │  │ │ 3 D7║
  ││   ──┤2 │  │ │  │││┌──┤D8│  │8├─────╢
  ││    3│  │  ├─┤ 7││││19├──┤  │ │     ║
  ││   ──┤3 │  │Co─┐││││┌─oE2│  │ │     ║
  ││     └──┴──┴─┘ ││││││1│  │  │ │     ║
  ││ ┌─────────────┘││││├─oE1│  │ │     ║
  ││ │      DD4     │││││ └──┴──┴─┘     ║
  ││ │  5┌──┬──┬─┐ 6│││││  /YCS         ║
  ││ └───oCa│CT│0├──┘│││└──────         ║
  ││   15├──┤  │ │11 │││                ║
  └──────/C │  │1├───┘││ ╔══════════════╝
   │   10│  │  │ │14  ││ ║
   └─────┤U/D  │2├────┘│ ║
        9├──┤  │ │ 2   │ ║
     ┌───┤R │  │3├─────┘ ║
     │  1│  │  │ │       ║
     ├───┤S │  │ │       ║
    ─┴─ 4│  │  │ │       ║
       ──┤0 │  │ │       ║
       12│  │  │ │       ║
       ──┤1 │  │ │       ║
       13│  │  │ │       ║
       ──┤2 │  │ │       ║
        3│  │  ├─┤ 7     ║
       ──┤3 │  │Co──     ║
         └──┴──┴─┘       ║
                    ╔════╝
          DD7.2     ║        DD8
RIGHB   5┌─┬──┐6  D0║A10 1┌─┬──┬─┐15
─────────┤D│|>├─────╫─────┤1│DC│0o──
        4│ │  │     ║A8  2│ │  │ │14
      ┌──oE│  │     ╟─────┤2│  │1o──
      │  └─┴──┘     ║A7  3│ │  │ │13
      │   DD7.3     ╟─────┤4│  │2o──
LEFTB │ 9┌─┬──┐8  D1║/RD 5├─┤  │ │12
─────────┤D│|>├─────╫─────o&│  │3o──
      │10│ │  │     ║A0  6│ │  │ │11 /BCS
      ├──oE│  │     ╟─────┤ │  │4o───────
      │  └─┴──┘     ║    4│ │  │ │10
      │   DD7.4     ║  ┌──oS│  │5o──
MIDLB │12┌─┬──┐11 D2║  │  │ │  │ │ 9 /XCS
─────────┤D│|>├─────╢  │  │ │  │6o───────
      │13│ │  │     ║  │  │ │  │ │ 7 /YCS
      ├──oE│  │     ║  │  │ │  │7o───────
      │  └─┴──┘     ║  │  └─┴──┴─┘
      │             ║  └────────────┐
      │   /BCS      ║        DD7.1  │
      └────────     ║/IORQ 2┌─┬──┐3 │
                    ╟───────┤D│|>├──┘
DD1..DD4 - К561ИЕ11 ║A5    1│ │  │
DD5, DD6 - К555АП5  ╟───────oE│  │
DD7      - К155ЛП8  ║       └─┴──┘
DD8      - К555ИД7

   Пpимечания:

- жиpной линией обозначена шина Spectrum;

- на мышь идут следующие сигналы: Xa, Xb,
  Ya, Yb, RIGHTB, MIDLB, LEFTB, +5V, GND;

- /BCS, /XCS, /YCS -  внутpенние   сигналы
  схемы,  соединяются с одноименными  паp-
  ными на схеме;

- схема пpиведена для мыши пассивного  ти-
  па (мышь для "Поиска" ММП-9B), для  дpу-
  гих необходимо вывести сигналы Xa, Xb  и
  Ya, Yb, котоpые беpутся с оптопаp  после
  цепочки тpанзистоp-тpиггеp Шмидта;

- в компьютеpе тpебуется  обеспечить  бло-
  киpовку поpта 0DFh;

- возможна замена схемы дешифpации (DD7.1,
  DD8) на ПЛМ-ку типа 556PТ4  (PТ11),  ос-
  тавшийся свободный выход может использо-
  ваться для блокиpовки поpтов.

   Если у  вас  есть  пожелания/наpекания,
вопpосы/идеи, то вы можете связаться с ав-
тоpом схемы Михаилом Кондpатьевым.

  Michael Kondratyev: 2:5030/362.1@FidoNet
                _  _  _

   Итак, тепеpь поясним, каким обpазом pа-
ботать с Kempston Mouse Interface пpогpам-
мисту. Hичего сложного  для  понимания  не
пpедвидится, поскольку интеpфейс  довольно
пpост и понятен. Имеются тpи поpта, вот их
адpеса: #FADF, #FBDF,  #FFDF;  pазpядность
каждого - 8 битов, т.е. байт.

 #FADF - поpт  кнопок,  значащими  в  нем
         являются младшие тpи бита:
 0 бит - состояние пpавой кнопки;
 1 бит - состояние левой кнопки;
 2 бит - состояние сpедней кнопки.

Пpи ненажатых кнопках все биты в `1'.  Пpи
нажатии на кнопку соответствующий бит  ус-
танавливается в `0'.

   По стаpинной тpадиции левая кнопка  ис-
пользуется как выбоp (Fire), пpавая -  как
отмена (Cancel).  Сpеднюю  кнопку  пpинято
использовать для дополнительных функций.

 #FBDF - поpт X-кооpдинаты;
 #FFDF - поpт У-кооpдинаты.

   По меpе пеpедвижения  мышь-манипулятоpа
значения в поpтах изменяются, пpичем еще и
циклически,  т.е.  пpи  достижении  #FF  и
дальшейшем увеличении становятся снова ну-
лем и pастут далее, опять до #FF. Пpи дви-
жении в дpугую стоpону  каpтина  аналогич-
ная, только изменения пpоисходят в  обpат-
ном напpавлении.

   Пpедставить это дело поможет вот  такая
картинка:
                y^.
                 │.
                 │2
                 │1
                 │012..
                 ┼─────────> x

   Таким  обpазом,  необходимо   считывать
значения поpтов, и по pазнице между  теку-
щим и  пpедыдущим  значением  опpеделяется
напpавление пеpемешения мышки.

   Пpи необходимости очень точных  манипу-
ляций дpайвеp пишется с  учетом  этого,  и
пеpемещение стpелочки на одну точку пpоиз-
водится пpи изменении значения,  считанно-
го из поpта на 2, 3, 5, или более единиц.

   В последнее вpемя стал модным более ум-
ный дpайвеp, котоpый в начале  ждет  нажа-
тия на кнопку, и пеpвая нажатая кнопка  на
мышке становится (для дpайвеpа) левой. Сие

относится только к двум  кpайним  кнопкам,
сpедняя кнопка - она и в  Афpике  сpедняя.
Это полезно для людей,  пpивыкших  деpжать
мышь в левой pуке, или на тот случай,  ес-
ли кто-то часто наступал на  вашу  мышь  и
одна из кнопок у нее  pаботает  хуже,  чем
остальные. Такой дpайвеp  считается  хоpо-
шим тоном. И если вы заметили, именно  так
поступает дpайвеp ZX-Format'а.

   Пpовеpить pаботу только-что  собpанного
интеpфейса можно пpямо из  Basic'а,  делая
PRINT IN из поpтов: 64479 - X, 65503 - Y -
пpи пеpемещении мыши значения должны изме-
няться циклически.  Пpи  чтении  из  поpта
64423 - Fire должны щелкаться тpи  младших
битика пpи нажатии кнопочек.

   И    напоследок  -  пpимеp     дpайвеpа
Kempston    Mouse,    используемого      в
ZX-Format'е:

;MOUSE DRIVER WITH FIRE BUTTON AUTOCONFIG
;(С) Andrey Rachkin'95

        JR       MDRV

DIRECTZ DEFB  0 ;FIRE
        DEFB  0 ;UP
        DEFB  0 ;DOWN
        DEFB  0 ;RIGHT
        DEFB  0 ;LEFT
        DEFB  0 ;CANCEL

MCOORD  DEFW  0 ;LAST CURSOR COORDS
                ;IN PIXELZ
MPORTS  DEFW  0 ;LAST READED MAUSY COORDS

NONDEF  AND   3 ;HERE COMEZ BUTTONZ
                ;CONTROL IF FIRE BUTON
                ;NOT DEFINED
        JR    Z,MDRV4 ;IF NONE BUTTON
                      ;PUSHED
        CP    1
        JR    Z,NONDEF_
        XOR   A

        LD    (MDRV3+2),A
        LD    A,5
        LD    (MDRV2+2),A
NONDEF_ LD    HL,0
        LD    (MDRV1),HL
        POP   IX

; ***** MAIN PROC OF MOUSEDRIVER *****
MDRV    PUSH  IX
        LD    HL,DIRECTZ
        PUSH  HL
        POP   IX
        XOR   A
        LD    (HL),A ;CLEARING
        INC   HL     ;OF
        LD    (HL),A ;DIRECTZ
        INC   HL     ;BUFER
        LD    (HL),A
        INC   HL
        LD    (HL),A
        INC   HL
        LD    (HL),A
        INC   HL
        LD    (HL),A

        INC   HL

        LD    BC,#FADF ;BUTTONZ CONTROL
        IN    A,(C)    ;READING FROM PORT
                       ;OF BUTTONS
        CPL
MDRV1   JR    NONDEF ;JR UNTIL FIRE
                     ;BUTTON NOT DEFINED
        RRA
MDRV2   RL    (IX+0) ;FIRE
        RRA
MDRV3   RL    (IX+5) ;CANCEL
; ***** COORDS CONTROL *****
MDRV4   LD    HL,(MCOORD) ;FORM LAST
                          ;CURSOR COORDS
        LD    DE,(MPORTS) ;FROM LAST
                          ;READED MOUSE
                          ;COORDS
        LD    BC,#FBDF
        IN    A,(C) ;READING FROM
                    ;PORT X-COORD (0-#FF)
        LD    (MPORTS),A
        SUB   E
        JR    Z,MDRV9

        JP    P,MDRV6
        LD    (IX+4),1 ;MOVE LEFT
        ADD   A,L
        JR    C,MDRV5
        XOR   A        ;MIN X-COORD
MDRV5   LD    L,A
        JR    MDRV9
MDRV6   ADD   A,L
        LD    (IX+3),1 ;MOVE RIGHT
        JR    C,MDRV7
        CP    #FE      ;MAX X-COORD
        JR    C,MDRV8
MDRV7   LD    A,#FE    ;MAX X-COORD
MDRV8   LD    L,A
MDRV9   LD    B,#FF
        IN    A,(C) ;READING FROM
                    ;PORT Y-COORD (0-#FF)
        LD    (MPORTS+1),A
        SUB   D
        JR    Z,MDRV14
        NEG
        JP    P,MDRV11
        LD    (IX+1),1 ;MOVE UP
        ADD   A,H

        JR    C,MDRV10
        XOR   A        ;MIN Y-COORD
MDRV10  LD    H,A
        JR    MDRV14
MDRV11  ADD   A,H
        LD    (IX+2),1 ;MOVE DOWN
        JR    C,MDRV12
        CP    #BF      ;MAX Y-COORD
        JR    C,MDRV13
MDRV12  LD    A,#BF    ;MAX Y-COORD
MDRV13  LD    H,A

MDRV14  LD    (MCOORD),HL ;NEW CURSOR
                          ;POSITION
                          ;IN PIXELZ
        POP      IX
        RET

; ***** DRIVER END *****

                 ─════─

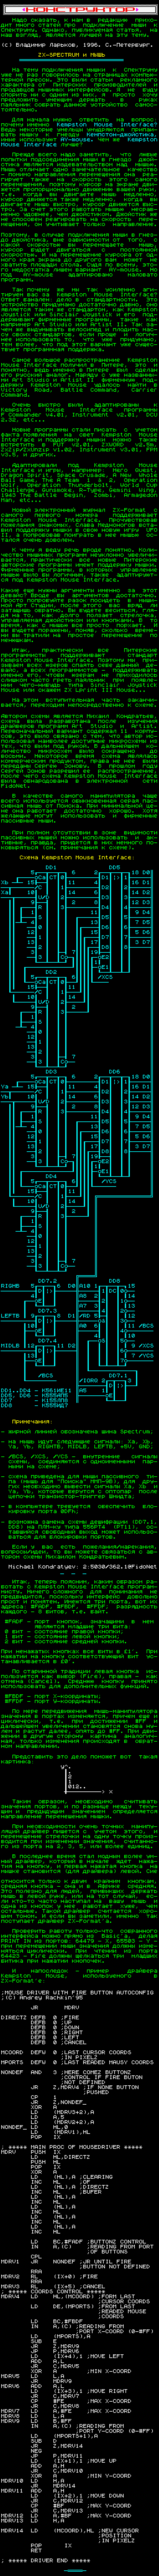
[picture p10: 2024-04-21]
history/spectrofon_20.png

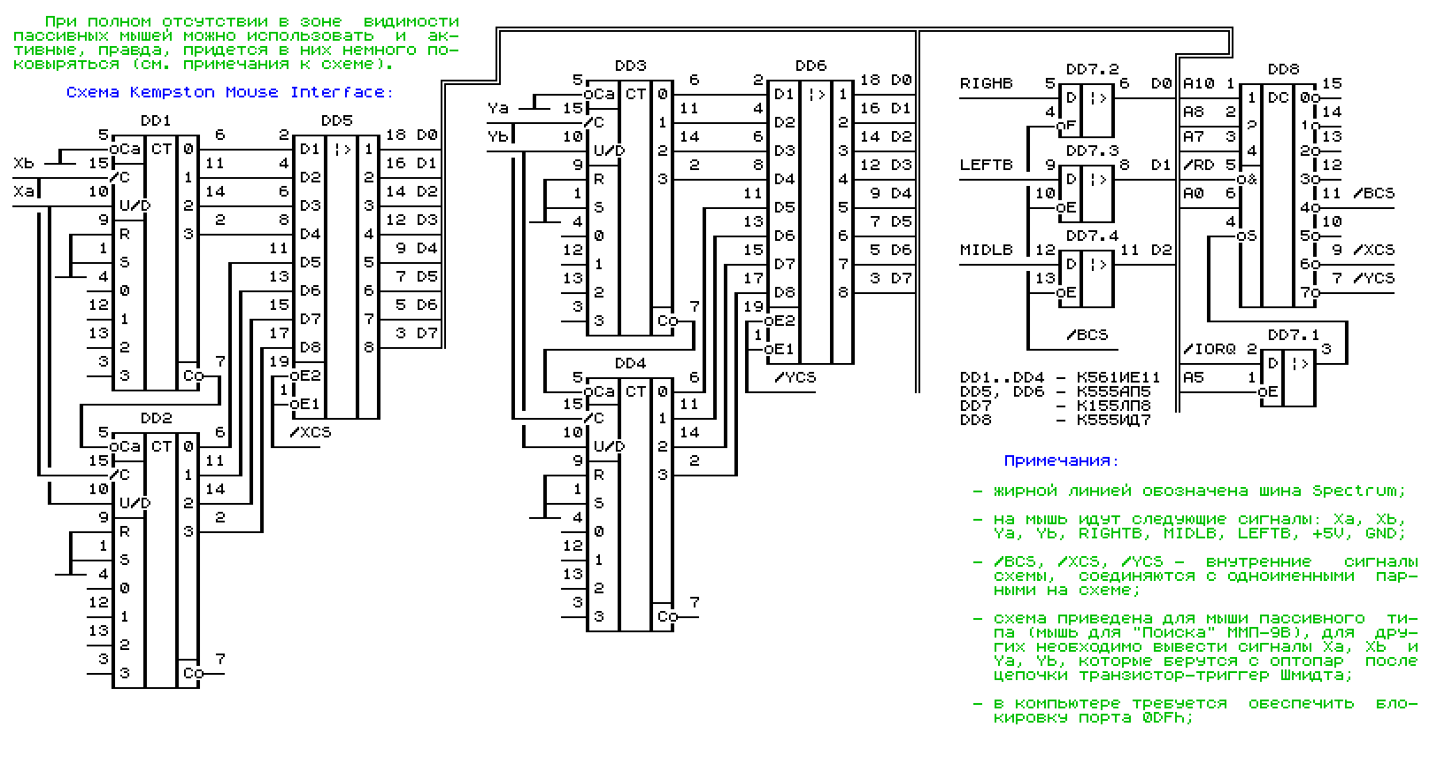
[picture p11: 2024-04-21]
history/spectrofon_20_kempston_mouse.png

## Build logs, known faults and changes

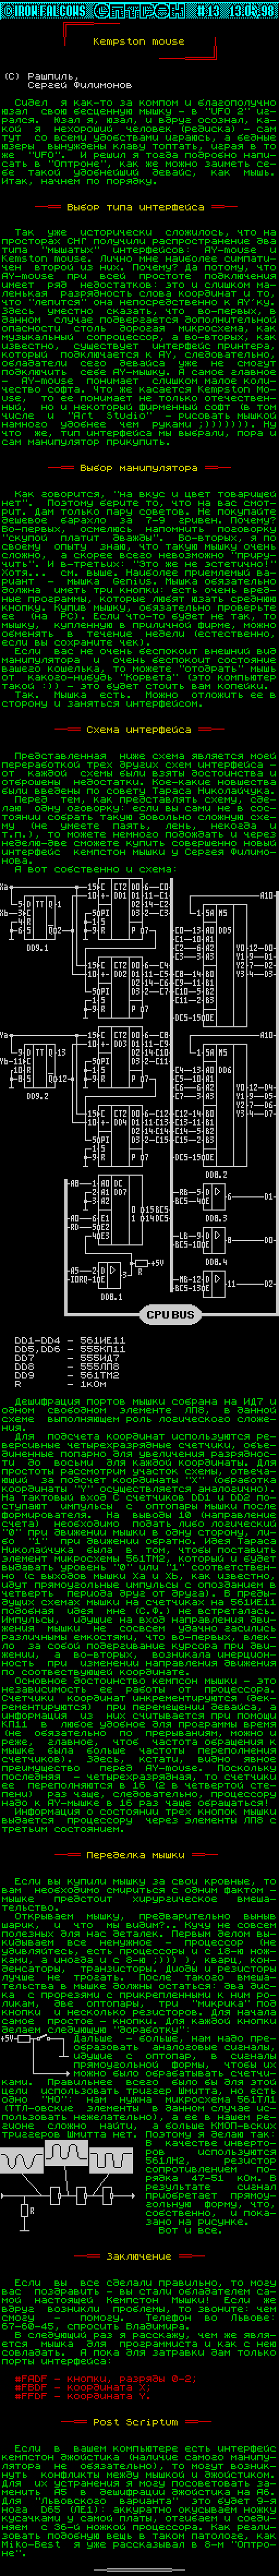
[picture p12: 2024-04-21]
history/optron_13.png

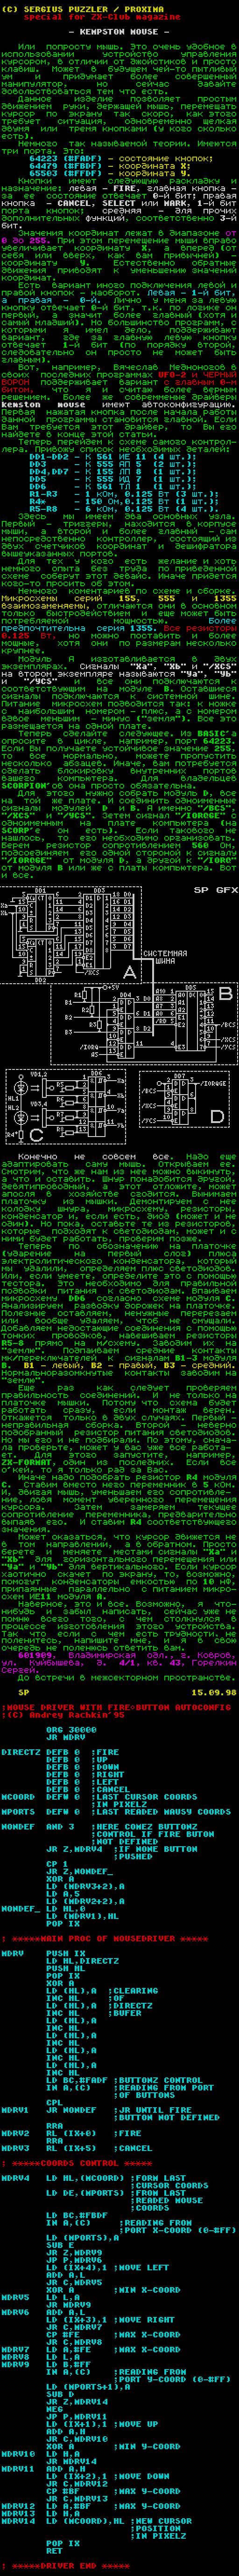
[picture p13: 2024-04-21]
history/zx-club_9.png

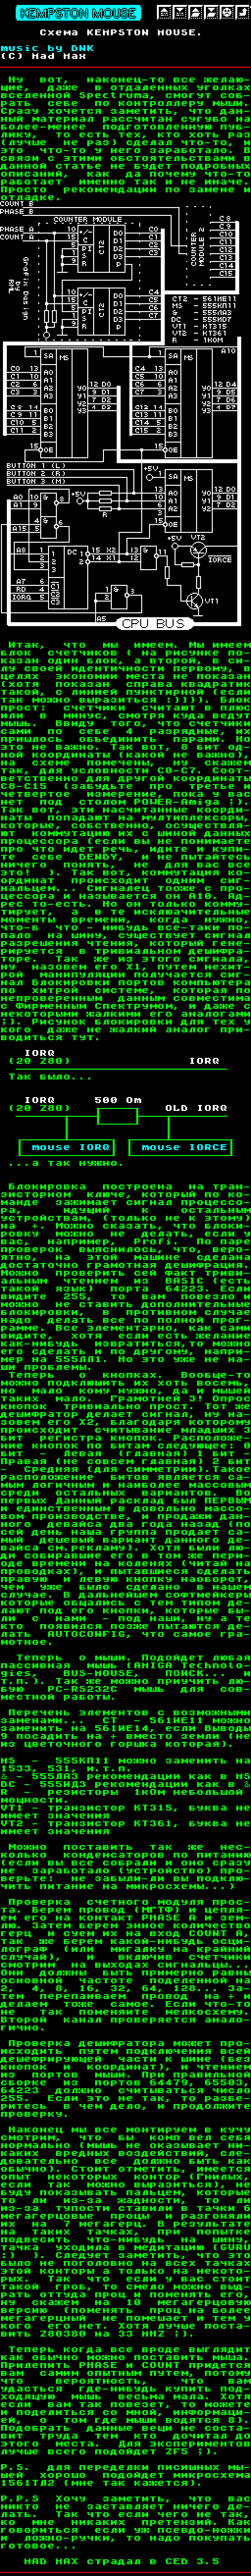
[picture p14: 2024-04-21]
history/zx-format_5.png

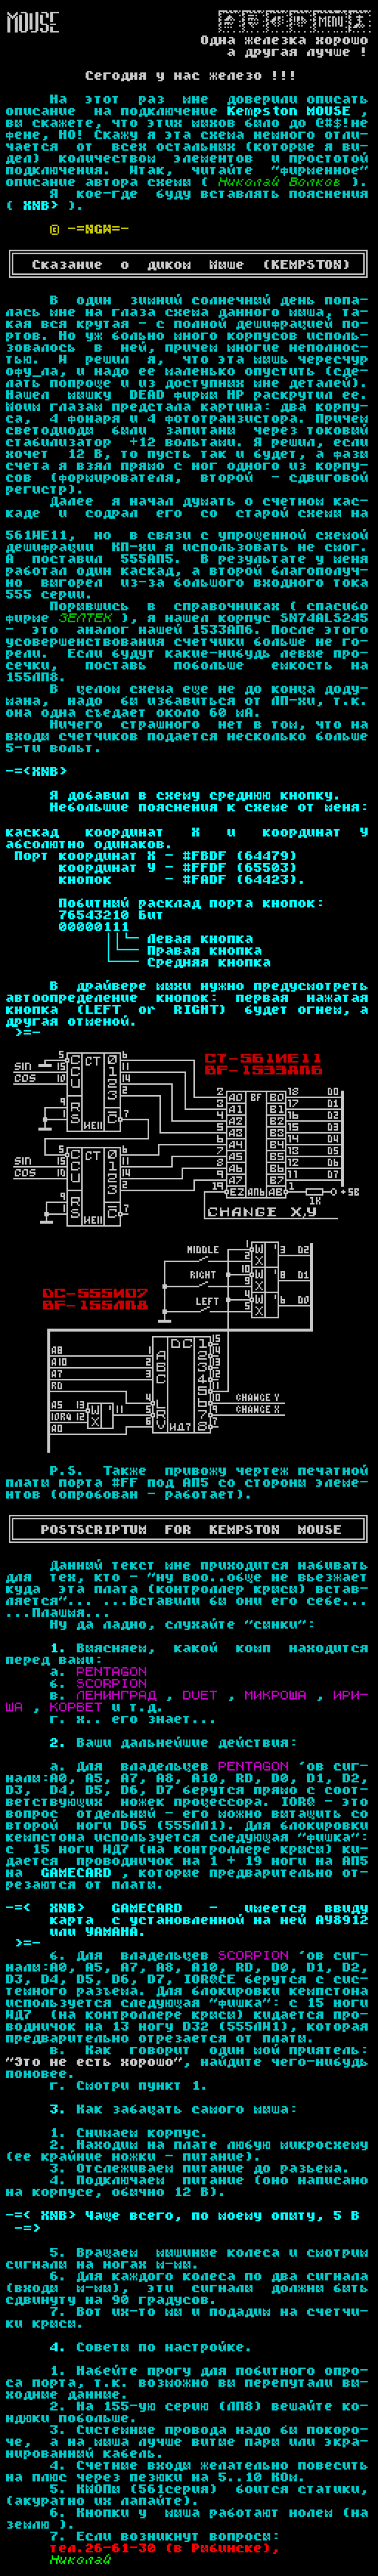
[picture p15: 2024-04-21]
history/adventurer_11.png

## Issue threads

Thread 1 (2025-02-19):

Gerbers for classic Spectrum/Sizif

Deboshnow, 2025-02-19:
Hello. Can you make a mouse board for the Classic ZX-Spectrum/Sizif-512?

proboterror, 2025-02-21:
Controller PCB edge connector can be directly soldered to Classic ZX-Spectrum ZX BUS SL-56 female slot connector, they are pin-to pin compatible.

Closed 2025-02-21.

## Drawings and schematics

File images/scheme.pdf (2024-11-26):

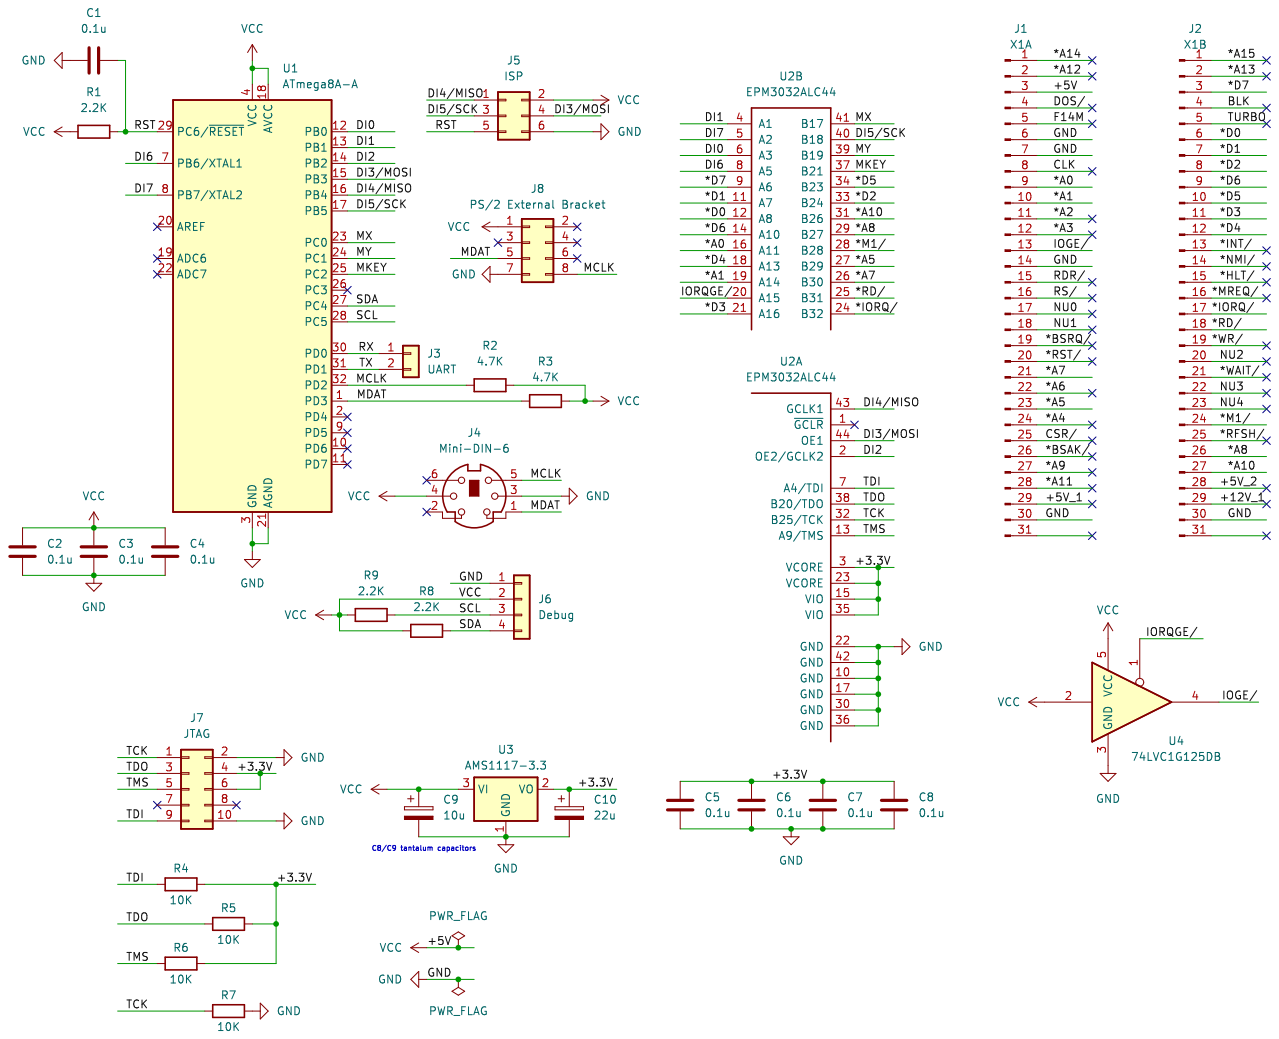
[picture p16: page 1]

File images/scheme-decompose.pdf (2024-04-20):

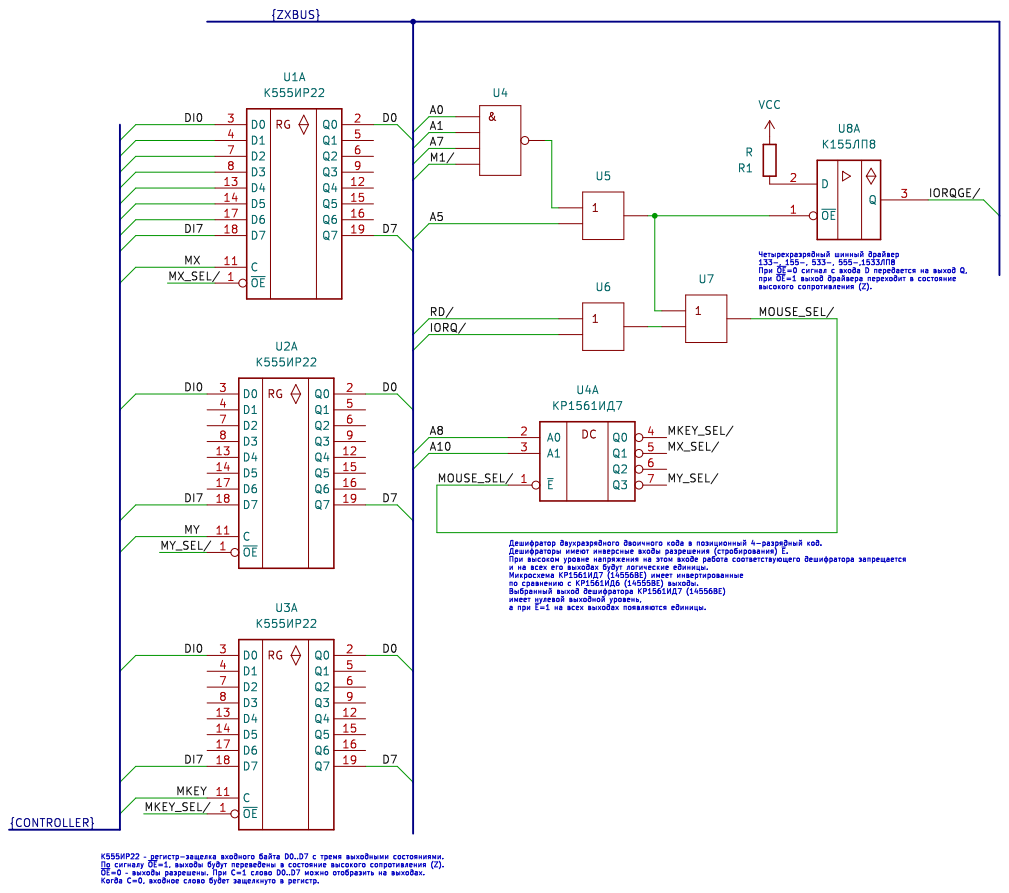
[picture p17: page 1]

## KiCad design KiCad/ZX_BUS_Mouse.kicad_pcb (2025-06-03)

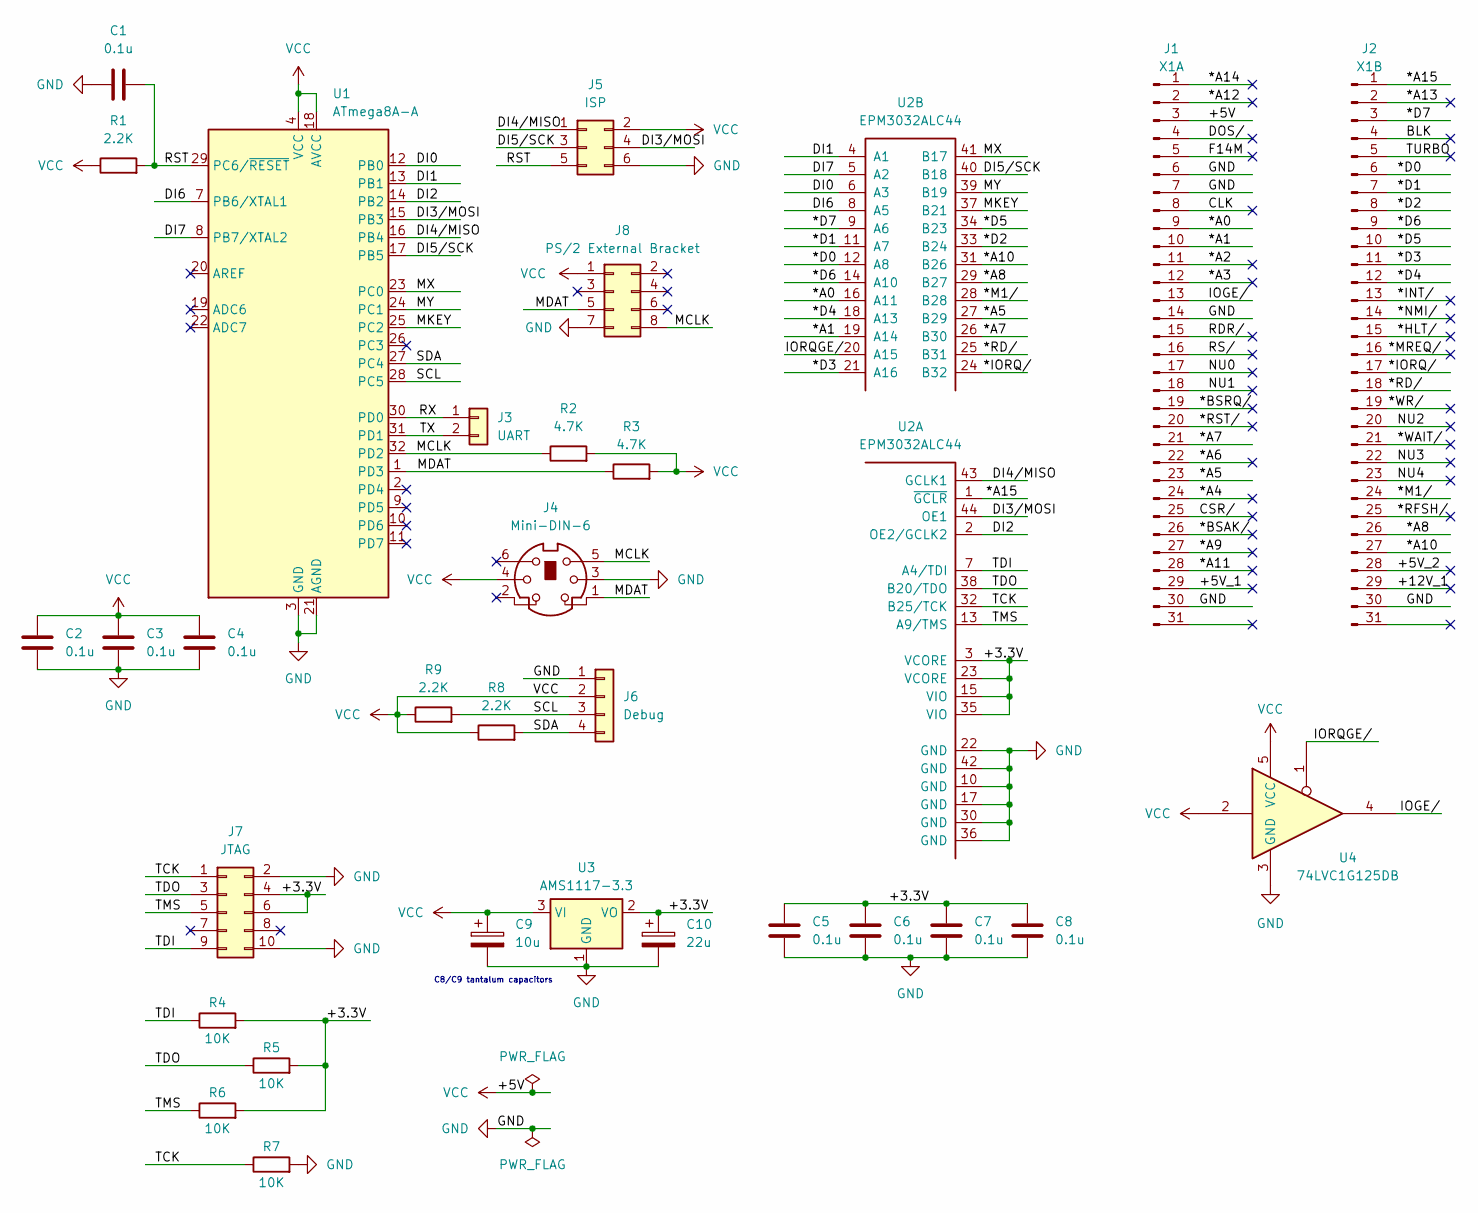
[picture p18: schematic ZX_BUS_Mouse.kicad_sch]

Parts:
C1, C2, C3, C4, C5, C6, C7, C8: 0.1u; C_1206_3216Metric_Pad1.33x1.80mm_HandSolder
C9: 10u; CP_EIA-6032-28_Kemet-C_Pad2.25x2.35mm_HandSolder
C10: 22u; CP_EIA-6032-28_Kemet-C_Pad2.25x2.35mm_HandSolder
J1: X1A; PinSocket_1x31_P2.54mm_2
J2: X1B; PinSocket_1x31_P2.54mm_2
J3: UART; PinHeader_1x02_P2.54mm_Vertical
J4: Mini-DIN-6; Connector_Mini-DIN_Female_6Pin_2rows
J5: ISP; PinHeader_2x03_P2.54mm_Vertical
J6: Debug; PinHeader_1x04_P2.54mm_Vertical
J7: JTAG; IDC-Header_2x05_P2.54mm_Vertical
J8: PS/2 External Bracket; PinHeader_2x04_P2.54mm_Vertical
R1, R8, R9: 2.2K; R_1206_3216Metric_Pad1.30x1.75mm_HandSolder
R2, R3: 4.7K; R_1206_3216Metric_Pad1.30x1.75mm_HandSolder
R4, R5, R6, R7: 10K; R_1206_3216Metric_Pad1.30x1.75mm_HandSolder
U1: ATmega8A-A; TQFP-32_7x7mm_P0.8mm
U2: EPM3032ALC44; PLCC-44_THT-Socket; MPN EPM3032ALC44-{grade}
U3: AMS1117-3.3; SOT-223-3_TabPin2
U4: 74LVC1G125DB; SOT-23-5_HandSoldering

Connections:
/*A0: J1.9, U2.16 (A11)
/*A1: J1.10, U2.19 (A14)
/*A2: J1.11
/*A3: J1.12
/*A4: J1.24
/*A5: J1.23, U2.27 (B29)
/*A6: J1.22
/*A7: J1.21, U2.26 (B30)
/*A8: J2.26, U2.29 (B27)
/*A9: J1.27
/*A10: J2.27, U2.31 (B26)
/*A11: J1.28
/*A12: J1.2
/*A13: J2.2
/*A14: J1.1
/*A15: J2.1, U2.1 (~GCLR)
/*BSAK/: J1.26
/*BSRQ/: J1.19
/*D0: J2.6, U2.12 (A8)
/*D1: J2.7, U2.11 (A7)
/*D2: J2.8, U2.33 (B24)
/*D3: J2.11, U2.21 (A16)
/*D4: J2.12, U2.18 (A13)
/*D5: J2.10, U2.34 (B23)
/*D6: J2.9, U2.14 (A10)
/*D7: J2.3, U2.9 (A6)
/*HLT/: J2.15
/*INT/: J2.13
/*IORQ/: J2.17, U2.24 (B32)
/*M1/: J2.24, U2.28 (B28)
/*MREQ/: J2.16
/*NMI/: J2.14
/*RD/: J2.18, U2.25 (B31)
/*RFSH/: J2.25
/*RST/: J1.20
/*WAIT/: J2.21
/*WR/: J2.19
/+3.3V: C5.1, C6.1, C7.1, C8.1, C10.1, J7.4, J7.6, R4.2, R5.2, R6.2, U2.3 (VCORE), U2.15 (VIO), U2.23 (VCORE), U2.35 (VIO), U3.2 (VO)
/+5V_1: J1.29
/+5V_2: J2.28
/+12V_1: J2.29
/BLK: J2.4
/CLK: J1.8
/CSR/: J1.25
/DI0: U1.12 (PB0), U2.6 (A3)
/DI1: U1.13 (PB1), U2.4 (A1)
/DI2: U1.14 (PB2), U2.2 (OE2/GCLK2)
/DI3/MOSI: J5.4, U1.15 (PB3), U2.44 (OE1)
/DI4/MISO: J5.1, U1.16 (PB4), U2.43 (GCLK1)
/DI5/SCK: J5.3, U1.17 (PB5), U2.40 (B18)
/DI6: U1.7 (PB6/XTAL1), U2.8 (A5)
/DI7: U1.8 (PB7/XTAL2), U2.5 (A2)
/DOS/: J1.4
/F14M: J1.5
/IOGE/: J1.13, U4.4
/IORQGE/: U2.20 (A15), U4.1
/MCLK: J4.5, J8.8, R2.1, U1.32 (PD2)
/MDAT: J4.1, J8.5, R3.1, U1.1 (PD3)
/MKEY: U1.25 (PC2), U2.37 (B21)
/MX: U1.23 (PC0), U2.41 (B17)
/MY: U1.24 (PC1), U2.39 (B19)
/NU0: J1.17
/NU1: J1.18
/NU2: J2.20
/NU3: J2.22
/NU4: J2.23
/RDR/: J1.15
/RST: C1.2, J5.5, R1.2, U1.29 (PC6/~RESET)
/RS/: J1.16
/RX: J3.1, U1.30 (PD0)
/SCL: J6.3, R9.2, U1.28 (PC5)
/SDA: J6.4, R8.2, U1.27 (PC4)
/TCK: J7.1, R7.1, U2.32 (B25/TCK)
/TDI: J7.9, R4.1, U2.7 (A4/TDI)
/TDO: J7.3, R5.1, U2.38 (B20/TDO)
/TMS: J7.5, R6.1, U2.13 (A9/TMS)
/TURBO: J2.5
/TX: J3.2, U1.31 (PD1)
GND: C1.1, C2.2, C3.2, C4.2, C5.2, C6.2, C7.2, C8.2, C9.2, C10.2, J1.6, J1.7, J1.14, J1.30, J2.30, J4.3, J5.6, J6.1, J7.2, J7.10, J8.7, R7.2, U1.3 (GND), U1.5 (GND), U1.21 (AGND), U2.10 (GND), U2.17 (GND), U2.22 (GND), U2.30 (GND), U2.36 (GND), U2.42 (GND), U3.1 (GND), U4.3 (GND)
VCC: C2.1, C3.1, C4.1, C9.1, J1.3, J4.4, J5.2, J6.2, J8.1, R1.1, R2.2, R3.2, R8.1, R9.1, U1.4 (VCC), U1.6 (VCC), U1.18 (AVCC), U3.3 (VI), U4.2, U4.5 (VCC)

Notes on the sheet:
C8/C9 tantalum capacitors

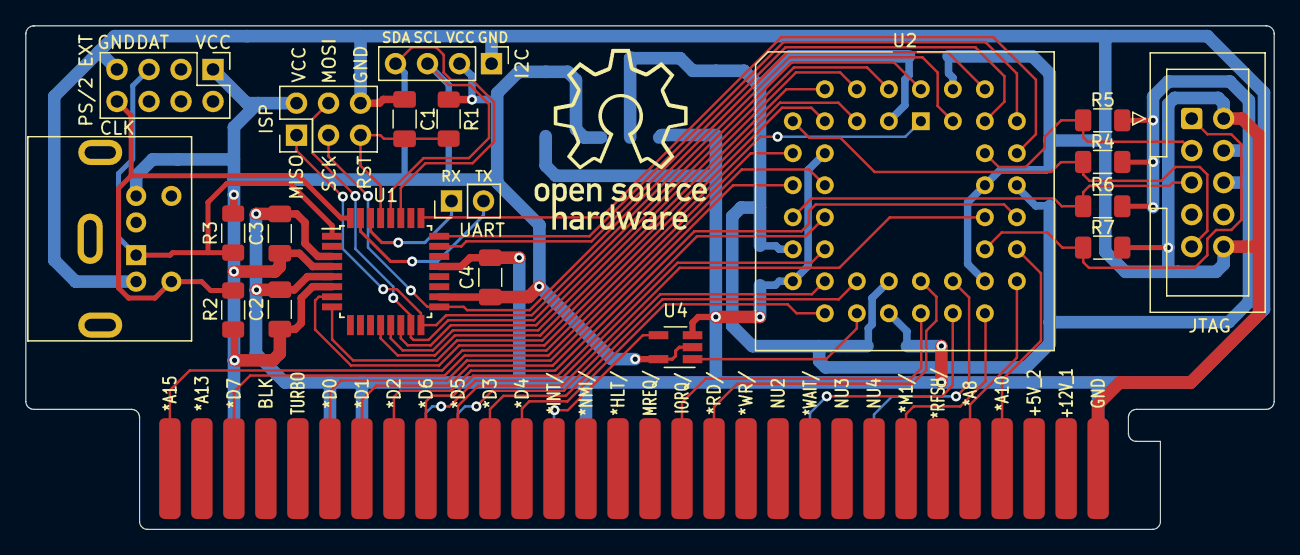
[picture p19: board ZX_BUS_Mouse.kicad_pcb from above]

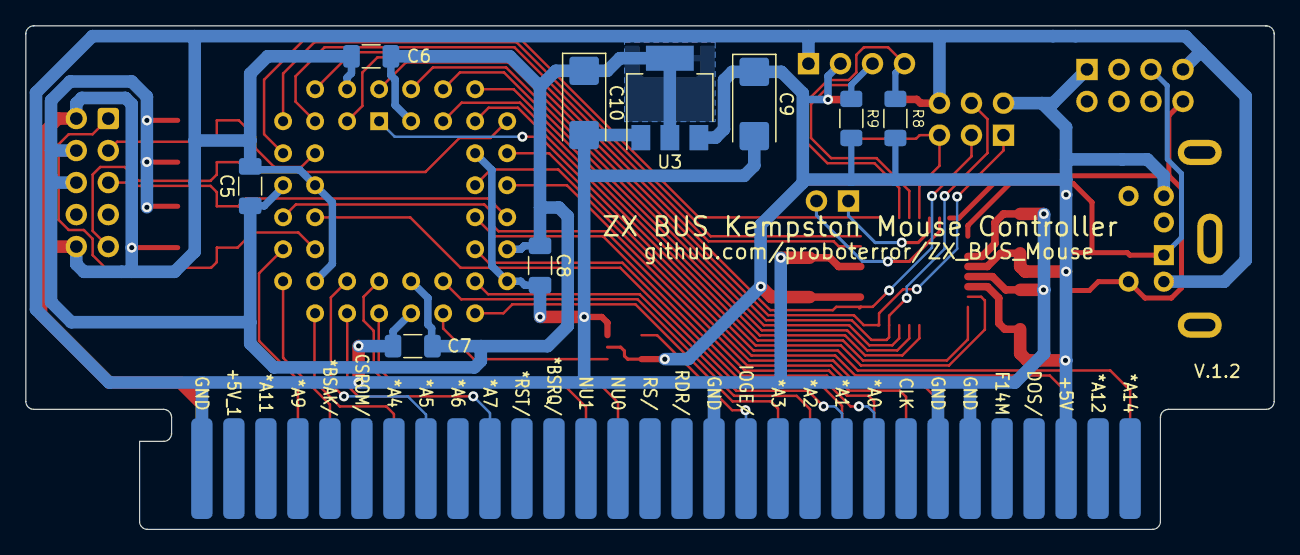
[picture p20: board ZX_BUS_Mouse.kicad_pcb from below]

Board: 2 copper layers, 99.1 x 40.0 mm, 31 parts (10 on the bottom side), 45 nets.

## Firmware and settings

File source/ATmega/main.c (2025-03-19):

/*
	PS/2 mouse support for ZX BUS Kempston Mouse Controller.
	Read PS/2 port mouse state from PS2_DATA_PIN / PS2_CLK_PIN
	and set Kempston mouse controller registers via DI_PORT and MX_PIN, MY_PIN, MKEY_PIN strobes.
	3 mouse buttons and 4 bit mouse wheel axis supported.

	Partially based on "Arduino/Wiring Library for interfacing with a PS2 mouse"
	https://github.com/kristopher/PS2-Mouse-Arduino

	Notable mention:
	https://github.com/svofski/mouse1351
	https://github.com/rucek/arduino-ps2-mouse
	https://github.com/trol73/avr-mouse-ps2-to-serial
	ZX Evolution ATmega128 peripheral controller avr source, http://svn.zxevo.ru/listing.php?repname=pentevo
*/

#if DEBUG
//Uses "OLED for AVR mikrocontrollers" library, https://github.com/Sylaina/oled-display
#include "lcd.h"
#endif

#include <stdlib.h>
#include <stdbool.h>
#include <stdint.h>

#include <avr/wdt.h>

#include <util/delay.h>

/*
	Reference:
	PS/2 Mouse/Keyboard Protocol (C) 1999, Adam Chapweske
	The PS/2 Mouse Interface (C) 2003 Adam Chapweske
	Keyboard/Auxiliary Device Controller - October 1990 (C) IBM Corp. 1990
*/

/*
Source: The PS/2 Mouse Interface by Adam Chapweske, 04/01/03

Movement Data Packet:

The standard PS/2 mouse sends movement/button information to the host using the following 3-byte packet (4): 

        Bit 7      Bit 6      Bit 5      Bit 4      Bit 3    Bit 2      Bit 1     Bit 0 
Byte 1  Y overflow X overflow Y sign bit X sign bit Always 1 Middle Btn Right Btn Left Btn
Byte 2                               X Movement
Byte 3                               Y Movement

Modes of Operation:

Data reporting is handled according to the mode in which the mouse is operating.  There are four standard modes of operation: 

- Reset - The mouse enters Reset mode at power-up or after receiving the "Reset" (0xFF) command. 
- Stream - This is the default mode (after Reset finishes executing) and is the mode in which most software uses the mouse.  If the host has previously set the mouse to Remote mode, it may re-enter Stream mode by sending the "Set Stream Mode" (0xEA) command to the mouse.
- Remote 
- Wrap 

Reset Mode:

The mouse enters reset mode at power-on or in response to the "Reset" (0xFF) command. After entring this mode, the mouse performs a diagnostic self-test referred to as BAT (Basic Assurance Test) and sets the following default values:

Sample Rate = 100 samples/sec
Resolution = 4 counts/mm
Scaling = 1:1
Data Reporting Disabled

It then sends a BAT completion code of either AAh (BAT successful) or FCh (Error). The host's response to a completion code other than AAh is undefined.
Following the BAT completion code (AAh or FCh), the mouse sends its device ID of 00h. This distinguishes it from a keyboard, or a mouse in an extended mode. I have read documents saything the host is not supposed to transmit any data until it receives a device ID.  However I've found that some BIOS's will send the "Reset" command immediately following the 0xAA received after a power-on reset.

After the mouse has sent its device ID to the host, it will enter Stream Mode.  Note that one of the default values set by the mouse is "Data Reporting Disabled".  This means the mouse will not issue any movement data packets until it receives the "Enable Data Reporting" command.

Stream Mode:

In stream mode, the mouse sends movement data when it detects movement or a change in state of one or more mouse buttons. The maximum rate at which this data reporting may occur is known as the sample rate.  This parameter ranges from 10 samples/sec to 200 samples/sec. Its default value is 100 samples/sec and the host may change that value by using the "Set Sample Rate" command.  Stream mode is the default mode of operation following reset.

Remote Mode:

In this mode the mouse reads its inputs and updates its counters/flags at the current sample rate, but it does not automatically issue data packets when movement has occured.  Instead, the host must poll the mouse using the "Read Data" command.  Upon receiving this command the mouse will send a single movement data packet and reset its movement counters.

Command Set:

The following is the set of command accepted by the standard PS/2 mouse.  If the mouse is in Stream mode, the host should disable data reporting (command F5h) before sending any other commands.

FFh (Reset) - The mouse responds to this command with "acknowledge" (FAh) then enters Reset Mode.
FEh (Resend) - The host sends this command whenever it receives invalid data from the mouse. The mouse responds by resending the last(2) packet(3) it sent to the host.   If the mouse responds to the "Resend" command with another invalid packet, the host may either issue another "Resend" command, issue an "Error" command, cycle the mouse's power supply to reset the mouse, or it may inhibit communication (by bringing the Clock line low).  The action taken depends on the host.
F6h (Set Defaults) - The mouse responds with "acknowledge" (FAh) then loads the following values:  Sampling rate = 100, Resolution = 4 counts/mm, Scaling = 1:1, Disable Data Reporting.  The mouse then resets its movement counters and enters stream mode.
F5h (Disable Data Reporting) - The mouse responds with "acknowledge" (FAh) then disables data reporting and resets its movement counters.  This only effects data reporting in Stream mode and does not disable sampling.  Disabled stream mode funcions the same as remote mode.
F4h (Enable Data Reporting) - The mouse responds with "acknowledge" (FAh) then enables data reporting and resets its movement counters.  This command may be issued while the mouse is in Remote Mode (or Stream mode), but it will only effect data reporting in Stream mode.
F3h (Set Sample Rate) - The mouse responds with "acknowledge" (FAh) then reads one more byte from the host.  The mouse saves this byte as the new sample rate. After receiving the sample rate, the mouse again responds with "acknowledge" (0xFA) and resets its movement counters.  Valid sample rates are 10, 20, 40, 60, 80, 100, and 200 samples/sec.
F2h (Get Device ID) - The mouse responds with "acknowledge" (FAh) followed by its device ID (00h for the standard PS/2 mouse.)  The mouse should also reset its movement counters.
F0h (Set Remote Mode) - The mouse responds with "acknowledge" (FAh) then resets its movement counters and enters remote mode.
EEh (Set Wrap Mode) - The mouse responds with "acknowledge" (FAh) then resets its movement counters and  enters wrap mode.
ECh (Reset Wrap Mode) - The mouse responds with "acknowledge" (FAh) then resets its movement counters and enters the mode it was in prior to wrap mode (Stream Mode or Remote Mode.)
EBh (Read Data) - The mouse responds with acknowledge (FAh) then sends a movement data packet. This is the only way to read data in Remote Mode.  After the data packets has been successfully sent, it resets its movement counters.
EAh (Set Stream Mode) - The mouse responds with "acknowledge" then resets its movement counters and enters steram mode.
E9h (Status Request) - The mouse responds with "acknowledge" then sends the following 3-byte status packet (then resets its movement counters.): 

       Bit 7     Bit 6 Bit 5  Bit 4   Bit 3    Bit 2    Bit 1      Bit 0
Byte 1 Always 0  Mode  Enable Scaling Always 0 Left Btn Middle Btn Right Btn
Byte 2                               Resolution
Byte 3                              Sample Rate

Right, Middle, Left Btn = 1 if button pressed; 0 if button is not pressed.
Scaling = 1 if scaling is 2:1; 0 if scaling is 1:1. (See commands E7h and E6h)
Enable = 1 if data reporting is enabled; 0 if data reporting is disabled. (See commands F5h and F4h)
Mode = 1 if Remote Mode is enabled; 0 if Stream mode is enabled. (See commands F0h and EAh)

E8h (Set Resolution) - The mouse responds with acknowledge (FAh) then reads one byte from the host and again responds with acknowledge (FAh) then resets its movement counters.  The byte read from the host determines the resolution as follows: 
 
Byte Read from Host  Resolution
0x00                 1 count/mm
0x01                 2 count/mm
0x02                 4 count/mm
0x03                 8 count/mm

E7h (Set Scaling 2:1) - The mouse responds with acknowledge (FAh) then enables 2:1 scaling
E6h (Set Scaling 1:1) - The mouse responds with acknowledge (FAh) then enables 1:1 scaling

The only commands the standard PS/2 mouse will send to the host are the "Resend" (FEh) and "Error" (FCh).  They both work the same as they do as host-to-device commands.

Intellimouse Extensions:

After power-on or reset the Microsoft Intellimouse operates just like a standard PS/2 mouse (ie, it uses a 3-byte movement data packet, responds to all commands in the same way as a standard PS/2 mouse, and reports a device ID of 00h.)  To enter "scrolling wheel" mode, the host sends the following command sequence:

Set sample rate 200
Set sample rate 100
Set sample rate 80

The host then issues the "Get device ID" command and waits for a response.  If a standard PS/2 mouse (ie, non-Intellimouse) is attached, it will respond with a device ID of 00h.  In this case, the host will recognize the fact that the mouse does have a scrolling wheel and will continue to treat it as a standard PS/2 mouse.  However, if a Microsoft Intellimouse is attached, it will respond with an ID of 03h.  This tells the host that the attached pointing device has a scrolling wheel and the host will then expect the mouse to use the following 4-byte movement data packet: 

        Bit 7      Bit 6      Bit 5      Bit 4      Bit 3    Bit 2      Bit 1     Bit 0 
Byte 1  Y overflow X overflow Y sign bit X sign bit Always 1 Middle Btn Right Btn Left Btn
Byte 2                               X Movement
Byte 3                               Y Movement
Byte 4                               Z Movement

Z Movement is a 2's complement number that represents the scrolling wheel's movement since the last data report.  Valid values are in the range of -8 to +7. This means the number is actually represented only by the least significant four bits.
*/

enum mouse_commands
{
	MOUSE_RESET = 0xFF, // Reset mouse
	MOUSE_RESEND = 0xFE, // Resend last data packet
	MOUSE_SET_DEFAULTS = 0xF6, // Set defaults
	MOUSE_DISABLE_DATA_REPORT = 0xF5, // Disable data reporting
	MOUSE_ENABLE_DATA_REPORT = 0xF4, // Enable data reporting
	MOUSE_SET_SAMPLE_RATE =  0xF3, // Set sample rate: mouse responds ACK, then reads one byte arg
	MOUSE_GET_DEVICE_ID = 0xF2, // Get device id
	MOUSE_SET_REMOTE_MODE = 0xF0, // Set remote mode
	MOUSE_SET_WRAP = 0xEE, // Set wrap mode
	MOUSE_RESET_WRAP = 0xEC, // Switch back to previous (remote or stream) mode
	MOUSE_REQUEST_DATA = 0xEB, // Request data in remote mode
	MOUSE_SET_STREAM = 0xEA, // Set stream mode (continuous reporting)
	MOUSE_STATUS_REQUEST = 0xE9, // Status request
	MOUSE_SET_RESOLUTION = 0xE8, // Set resolution
	MOUSE_SET_SCALE_21 = 0xE7, // Set scaling 2:1
	MOUSE_SET_SCALE_11 = 0xE6, // Set scaling 1:1
};

enum mouse_response
{
	MOUSE_ACK = 0xFA, // Reset acknowledge OK
	MOUSE_NAK = 0xFE, // Reset acknowledge fail
	MOUSE_ERROR = 0xFC, // Mouse error
	MOUSE_RESET_OK = 0xAA, // Post-reset self test passed
};

enum mouse_resolution
{
	RESOLUTION_1_COUNTS_PER_MM = 0,
	RESOLUTION_2_COUNTS_PER_MM = 1,
	RESOLUTION_4_COUNTS_PER_MM = 2,
	RESOLUTION_8_COUNTS_PER_MM = 3
};

#define DEFAULT_MOUSE_DEVICE_ID 0
#define INTELLIMOUSE_DEVICE_ID 3

// Valid sample rates are 10, 20, 40, 60, 80, 100, and 200 samples/sec.
#define PS2_SAMPLES_PER_SEC 60

#define PS2_DATA_PORT D
#define PS2_DATA_PIN 3
#define PS2_CLK_PORT D
#define PS2_CLK_PIN 2

#define DI_PORT B
#define MX_PORT C
#define MX_PIN 0
#define MY_PORT C
#define MY_PIN 1
#define MKEY_PORT C
#define MKEY_PIN 2

#define GLUE(a, b) a##b
#define DDR(p) GLUE(DDR, p)
#define PORT(p) GLUE(PORT, p)
#define PIN(p) GLUE(PIN, p)

// DDRx Register: 1 makes the corresponding pin an output, and a 0 makes the corresponding pin an input.
#define input(PORT_, PIN_) DDR(PORT_) &= ~(1 << PIN_);
#define output(PORT_, PIN_) DDR(PORT_) |= (1 << PIN_)

/*
The PORTx Register
The PORTx register functions differently depending on whether a pin is set to input or output. The simpler case is if a pin is set to output. Then, the PORTC register, for example, controls the value at the physical IO pins on Port C.
When a pin is set to be an input, PORTx register DOES NOT contain the logic values applied to the pins. We use the PINx register for that. If a pin is an input, a 1 in the PORTx register sets a pull-up resistor.
*/
#define low(PORT_, PIN_) PORT(PORT_) &= ~(1 << PIN_)
#define high(PORT_, PIN_) PORT(PORT_) |= (1 << PIN_)

#define CLK_READ ((PIN(PS2_CLK_PORT) >> PS2_CLK_PIN) & 0x1)
#define DATA_READ ((PIN(PS2_DATA_PORT) >> PS2_DATA_PIN) & 0x1)

#define DI_BUS_SET_DELAY 1
#define REGISTER_SET_DELAY 1

// Kempston mouse interface axis data, increased by reported PS/2 mouse axis coordinate delta.
// 8-bit values are wrapped and not clamped.
uint8_t mouse_x = 128;
uint8_t mouse_y = 96;
// Value read from PS/2 mouse data packet. Should be inverted for Kempston mouse.
// Bit 2: middle button, bit 1: right button, bit 0: left button.
// Unlike PS/2 mouse, Kempston mouse can have 4 buttons.
uint8_t mouse_buttons = 0;

#if ENABLE_WHEEL
bool mouse_wheel_enabled = false; // Mouse wheel present flag.
/*
Absolute mouse wheel axis value.
0b0000 by default if mouse wheel presented else 0b1111.
Increased / decreased by reported mouse wheel delta.
Matched Unreal Speccy 0.39.0 behaviour.
References:
https://groups.google.com/g/fido7.real.speccy/c/Qeid4aFhjRg
https://groups.google.com/g/fido7.zx.spectrum/c/vpr8vh2X2sA
https://zxpress.ru/article.php?id=6538 (DonNews #19)
https://velesoft.speccy.cz/kmouse/km-doc/kempston_mouse_turbo_interface/km-t_2011/k-mouse2011-doc.pdf
*/
int8_t mouse_z = 0b00000000;
#endif

typedef enum
{
	PS2_STATE_ERROR,
	PS2_STATE_OK
} ps2_state_t;

ps2_state_t ps2_state = PS2_STATE_OK;

typedef enum
{
	MCLK,
	MDATA
} mouse_pin_t;

// PS/2 interface data and clock lines are both open collector.
// Configuring port as input (DDRx register) switches it to high impendance mode,
// writing high to PORTx register enables internal weak pull-up resistor.
void gohi(mouse_pin_t pin)
{
	switch (pin)
	{
	case MDATA:
		high(PS2_DATA_PORT, PS2_DATA_PIN);
		input(PS2_DATA_PORT, PS2_DATA_PIN);
		break;
	case MCLK:
		high(PS2_CLK_PORT, PS2_CLK_PIN);
		input(PS2_CLK_PORT, PS2_CLK_PIN);
		break;
	};
}

// Port configured as output and connected to ground.
void golo(mouse_pin_t pin)
{
	switch (pin)
	{
	case MDATA:
		low(PS2_DATA_PORT, PS2_DATA_PIN);
		output(PS2_DATA_PORT, PS2_DATA_PIN);
		break;
	case MCLK:
		low(PS2_CLK_PORT, PS2_CLK_PIN);
		output(PS2_CLK_PORT, PS2_CLK_PIN);

		break;
	};
}

// Data sent from the host to the device is read on the rising edge of the clock signal.
void mouse_write_bit(const uint8_t bit)
{
	if (bit)
	{
		gohi(MDATA);
	}
	else
	{
		golo(MDATA);
	}
	/* wait for clock cycle */
	while (CLK_READ == 0) {}
	while (CLK_READ == 1) {}
}

/*
The PS/2 Mouse/Keyboard Protocol
http://www.computer-engineering.org/ps2protocol/

Host-to-Device Communication:

PS/2 device always generates the clock signal. If the host wants to send data, it must first put the Clock
and Data lines in a "Request-to-send" state as follows:

* Inhibit communication by pulling Clock low for at least 100 microseconds.
* Apply "Request-to-send" by pulling Data low, then release Clock.

The device should check for this state at intervals not to exceed 10 milliseconds. When the device detects this state, it will begin generating Clock signals and clock in eight data bits and one stop bit. The host changes the Data line only when the Clock line is low, and data is read by the device when Clock is high.

After the stop bit is received, the device will acknowledge the received byte by bringing the Data line low and generating one last clock pulse. 

Steps the host must follow to send data to a PS/2 device:
 1) Bring the Clock line low for at least 100 microseconds.
 2) Bring the Data line low.
 3) Release the Clock line.
 4) Wait for the device to bring the Clock line low.
 5) Set/reset the Data line to send the first data bit
 6) Wait for the device to bring Clock high.
 7) Wait for the device to bring Clock low.
 8) Repeat steps 5-7 for the other seven data bits and the parity bit
 9) Release the Data line.
 10) Wait for the device to bring Data low.
 11) Wait for the device to bring Clock low.
 12) Wait for the device to release Data and Clock
*/
void mouse_write_byte(uint8_t data)
{
	uint8_t parity = 1;

	// Inhibit communication with CLK = low.
	golo(MCLK);
	_delay_us(100);

	// start bit = 0
	golo(MDATA);
	_delay_us(10);
	gohi(MCLK);

	/* wait for mouse to take control of clock); */
	while (CLK_READ == 1) {}
	/* clock is low, and we are clear to send data */

	for (uint8_t i = 0; i < 8; i++)
	{
		mouse_write_bit(data & 0x01);

		parity = parity ^ (data & 0x01);
		data = data >> 1;
	}

	mouse_write_bit(parity);

	// stop bit = 1
	gohi(MDATA);
	_delay_us(50);

	while (CLK_READ == 1) {}
	/* wait for mouse to switch modes */
	while ((CLK_READ == 0) || (DATA_READ == 0)) {} // Device should confirm with ACK bit = 0.

	// put a hold on the incoming data / inhibit the auxiliary device
	golo(MCLK);
}

// Data sent from the device to the host is read on the falling edge of the clock signal.
uint8_t mouse_read_bit(void)
{
	// The Data line changes state when Clock is high and that data is valid when Clock is low.
	// Wait CLK down
	while (CLK_READ == 1) {}

	const uint8_t bit = DATA_READ;

	// Wait CLK up
	while (CLK_READ == 0) {}

	return bit;
}

uint8_t mouse_read_byte(void)
{
	uint8_t data = 0;
	uint8_t parity = 1;

	// Release clock and data lines.
	gohi(MCLK);
	gohi(MDATA);
	// The clock line must be continuously high for at least 50 microseconds
	// before the device can begin to transmit data.
	_delay_us(50);

	const uint8_t start_bit = mouse_read_bit(); // Start bit should be 0
	if(start_bit == 1)
		ps2_state = PS2_STATE_ERROR;

	for (uint8_t i = 0; i < 8; i++)
	{
		data >>= 1;

		const uint8_t bit = mouse_read_bit();
		if(bit)
			data |= 0x80;
		parity = parity ^ (bit & 0x01);
	}

	const uint8_t parity_bit = mouse_read_bit(); // Parity bit (odd parity)
	if (parity != (parity_bit != 0))
		ps2_state = PS2_STATE_ERROR;

	const uint8_t stop_bit = mouse_read_bit(); // Stop bit should be 1
	if(stop_bit == 0)
		ps2_state = PS2_STATE_ERROR;

	/* put a hold on the incoming data. */
	golo(MCLK);

	return data;
}

void mouse_write_byte_read_ack(const uint8_t data)
{
	mouse_write_byte(data);

	if (mouse_read_byte() != MOUSE_ACK)
	{ 
		ps2_state = PS2_STATE_ERROR; 
	}
}
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
int main(void)
{
	// Set CPLD ports to output.
	DDR(DI_PORT) = 0xFF;
	output(MX_PORT, MX_PIN);
	output(MY_PORT, MY_PIN);
	output(MKEY_PORT, MKEY_PIN);

	low(MX_PORT, MX_PIN);
	low(MY_PORT, MY_PIN);
	low(MKEY_PORT, MKEY_PIN);

	// Set initial MX, MY, MKEY values to CPLD controller registers. Changed after first PS/2 mouse event packet received.
	// Data written to registers on rising_edge.
	// Questionable, some code attempting to detect Kempston mouse presence by checking X=Y=0xFF, some other by checking X!=Y or buttons=0b111.
	// Actually there is no reliable method to detect Kempston mouse presence.

	PORT(DI_PORT) = 0x80;
	_delay_us(DI_BUS_SET_DELAY);
	high(MX_PORT, MX_PIN);
	_delay_us(REGISTER_SET_DELAY);
	low(MX_PORT, MX_PIN);

	PORT(DI_PORT) = 0x60;
	_delay_us(DI_BUS_SET_DELAY);
	high(MY_PORT, MY_PIN);
	_delay_us(REGISTER_SET_DELAY);
	low(MY_PORT, MY_PIN);

	PORT(DI_PORT) = 0xFF;
	_delay_us(DI_BUS_SET_DELAY);
	high(MKEY_PORT, MKEY_PIN);
	_delay_us(REGISTER_SET_DELAY);
	low(MKEY_PORT, MKEY_PIN);

#if DEBUG
	lcd_init(LCD_DISP_ON); // init lcd and turn on

	lcd_gotoxy(0, 2);
	lcd_puts("Init...");
#endif
	// Reboot controller in case of init lock.
	// Microsoft Mouse Port Compatible Mouse 2.1A (FCC ID: C3KKS8, Part No 92841): takes more than 1s to init after power on.
	// Logitech M-SBF96 (P/N 852209-A000): requires 1s delay after power on before init.
	wdt_enable(WDTO_2S);

	mouse_init();

	wdt_disable();

#if DEBUG
	lcd_puts("Done");
#endif

#if DEBUG
	lcd_gotoxy(0, 3);
#if ENABLE_WHEEL
	if (mouse_wheel_enabled)
	{
		lcd_puts("Intellimouse mode");
	}
	else
#endif
	{
		lcd_puts("Standard mode");
	}
#endif // DEBUG

	while (1)
	{
		mouse_buttons = mouse_read_byte();
		int8_t dx = (int8_t)mouse_read_byte();
		int8_t dy = (int8_t)mouse_read_byte();
		mouse_x += dx;
		mouse_y += dy;
#if ENABLE_WHEEL
		if (mouse_wheel_enabled)
		{
			mouse_z -= (int8_t)mouse_read_byte(); // Axis direction matched Unreal Speccy 0.39.0 behaviour.
			mouse_z &= 0b00001111;
		}
#endif
		// Set MX, MY, MKEY values to controller registers.
		// Data written to registers on rising_edge.
		PORT(DI_PORT) = mouse_x;
		_delay_us(DI_BUS_SET_DELAY);
		high(MX_PORT, MX_PIN);
		_delay_us(REGISTER_SET_DELAY);
		low(MX_PORT, MX_PIN);

		PORT(DI_PORT) = mouse_y;
		_delay_us(DI_BUS_SET_DELAY);
		high(MY_PORT, MY_PIN);
		_delay_us(REGISTER_SET_DELAY);
		low(MY_PORT, MY_PIN);

#if ENABLE_WHEEL
		PORT(DI_PORT) = (~mouse_buttons & 0b00000111) | (mouse_z << 4) | (0b00001000); // Bit 4 is 4th mouse button (not pressed)
#else
		PORT(DI_PORT) = (~mouse_buttons & 0b00000111) | (0b11111000); // Unused port bits set to 1 (mouse_z axis, 4th mouse button)
#endif
		_delay_us(DI_BUS_SET_DELAY);
		high(MKEY_PORT, MKEY_PIN);
		_delay_us(REGISTER_SET_DELAY);
		low(MKEY_PORT, MKEY_PIN);

#if DEBUG
		char buf[5];
		lcd_gotoxy(0, 0);
		itoa(mouse_x, buf, 10);
		lcd_puts(buf);
		lcd_puts(" ");
		itoa(mouse_y, buf, 10);
		lcd_puts(buf);
		lcd_puts(" ");
#if ENABLE_WHEEL
		itoa(mouse_z, buf, 10);
		lcd_puts(buf);
		lcd_puts(" ");
#endif
		itoa((mouse_buttons & 0b00000111), buf, 10);
		lcd_puts(buf);
#endif // DEBUG

		if (ps2_state == PS2_STATE_ERROR)
		{
			wdt_enable(WDTO_1S); // Reboot controller in case of error.
		}
	};

	return 0;
}

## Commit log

2024-04-19 ZX Bus Mouse controller inital schematic. Schematic borrowed from Deltagon 1.5 (C) @djking26, Игорь Матвеев @azx987sa. ZX Bus prototype PCB from https://github.com/AlexEkb4ever/ZX_BUS Altera MAX 3000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
    Changes from:
    Added ATmega ISP connector, debug screen I2C connector.
    Decoupling capacitors for each ATmega / Altera power line.
    Optional capacitor on ATmera RESET.
    Tantalum capacitors for AM51117 input / output.
    OIRQ input split to IORQ input / IOGE output.
    [ZX_BUS_Mouse.kicad_pcb, ZX_BUS_Mouse.kicad_sch]
2024-04-19 Route PCB. Reassign EPM3032 IO pins.
    [ZX_BUS_Mouse.kicad_pcb, ZX_BUS_Mouse.kicad_sch]
2024-04-19 Correct SDA pullup resistor.
    [ZX_BUS_Mouse.kicad_sch]
2024-04-19 Add debug I2C connector on PCB. Disable solder mask on edge connector.
    [ZX_BUS_Mouse.kicad_pcb, ZX_BUS_Mouse.kicad_sch]
2024-04-19 Board height 40 mm.
    [ZX_BUS_Mouse.kicad_pcb]
2024-04-19 Connect I2C to VCC and GND.
    [ZX_BUS_Mouse.kicad_pcb]
2024-04-19 Add labels to PCB.
    [ZX_BUS_Mouse.kicad_pcb]
2024-04-19 Arrange resistors references.
    [ZX_BUS_Mouse.kicad_pcb, ZX_BUS_Mouse.kicad_sch]
2024-04-19 Add logo to PCB.
    [ZX_BUS_Mouse.kicad_pcb]
2024-04-19 Remove unused 2x30 connector from PCB.
    [ZX_BUS_Mouse.kicad_sch]
2024-04-19 Align PCB F.Fab labels.
    [ZX_BUS_Mouse.kicad_pcb]
2024-04-19 Add reference url: https://github.com/4x1md/kicad_libraries/blob/master/Custom_Footprints.pretty/Connector_Mini-DIN_Female_6Pin_2rows.kicad_mod
2024-04-19 Rename libs/my_lib.pretty libs/zx_bus.pretty.
    [ZX_BUS_Mouse.kicad_pcb, ZX_BUS_Mouse.kicad_sch]
2024-04-19 Rename my_lib library to zx_bus. Move Connector_Mini-DIN_Female_6Pin.pretty to libs/.
2024-04-19 Move to KiCad/ folder.
    [ZX_BUS_Mouse.kicad_pcb, ZX_BUS_Mouse.kicad_sch]
2024-04-19 Test production gerbers.
    [ZX_BUS_Mouse-B_Cu.gbl, ZX_BUS_Mouse-B_Mask.gbs, ZX_BUS_Mouse-B_Paste.gbp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]
2024-04-19 Move to gerber/ folder.
    [ZX_BUS_Mouse-B_Cu.gbl, ZX_BUS_Mouse-B_Mask.gbs, ZX_BUS_Mouse-B_Paste.gbp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]
2024-04-19 Initial PS/2 mouse support with mouse wheel. Implementation without PS/2 clock signal change interrupt usage. https://github.com/Sylaina/oled-display used for debug OLED screen output. Makefile to be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
    [main.c]
2024-04-19 Add ZX Bus interface registers data output. Fix compiler warnings.
    [main.c]
2024-04-19 Fixed PS/2 mouse init after power on. Invert mouse buttons state values. Check and match mouse wheel / buttons / axis behaviour with available specs and Unreal Speccy 0.39.0. Set initial Kempston mou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
    Add Kempston mouse wheel support references.
    Move ENABLE_WHEEL define to Makefile.
    Change mouse axis data to uint8_t.
    Replace delays magic numbers with named defines.
    Replace defines with typed enum mouse_pin_t.
    Add debug messages for PS/2 i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
    [main.c]
2024-04-19 Mouse controller initial VHDL implementation. No mouse wheel support. 31 of 32 macrocells, 33 of 34 IO pins used. Deltagon IO pins assinments.
2024-04-19 Pin assignment matching PCB.
2024-04-19 Fixed #FADF mouse buttons port. Assume output is always 8-bit wide. Unused data bits in output should be set to 1.
2024-04-19 Add example for enable mouse wheel. Cleanup outdated comments.
2024-04-20 Update PCB dimensions drawings.
    [ZX_BUS_Mouse.kicad_pcb]
2024-04-20 Add reference Deltagon 1.5 mouse controller schematic.
2024-04-20 Add board photos.
2024-04-22 Set MKEY register mouse wheel bits to 1111 if mouse wheel not presented.
2024-09-20 Fix PCB backface ZX-BUS pins silkscreen labels.
    [ZX_BUS_Mouse.kicad_pcb]
2024-09-20 Update PCB images.
2024-09-20 Update gerbers.
    [ZX_BUS_Mouse-B_Silkscreen.gbo, ZX_BUS_Mouse-F_Silkscreen.gto]
2024-11-26 Add 74LVC1G125DB 3-state buffer for IORQGE/IOGE signal: 5V output signal level. Resolve issue with ZX-BUS XTRaiser, prevent potential issues with 5V IORQGE back current from other cards to CPLD outpu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
    [ZX_BUS_Mouse.kicad_pcb, ZX_BUS_Mouse.kicad_sch]
2024-11-26 Add external PS/2 mouse bracket connector (common 486-Pentium AT motherboards pinout). Add debug UART connector (RX/TX). Move I2C debug connector, move optional R8, R9 pullup resistors to backside. C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
    [ZX_BUS_Mouse.kicad_pcb, ZX_BUS_Mouse.kicad_sch]
2024-11-26 Fix schematic ERC warnings.
    [ZX_BUS_Mouse.kicad_sch]
2024-11-26 Extend ZX-BUS edge connector width from 80 to 81 mm (+0.5 mm from right and left).
    Reference:
    IBM 5150 Technical Reference manual, page 54
    http://www.minuszerodegrees.net/manuals/IBM_5150_Technical_Reference_6322507_APR84.pdf
    [ZX_BUS_Mouse.kicad_pcb]
2024-11-27 Replace CPLD VHDL implementation with simplified Verilog one. Optimize to 32 macrocells used with 3rd mouse button disabled.
2025-02-11 Set initial Kempston mouse controller register values: MX: 0x80, MY: 0x60, MKEY: 0xFF (Mr Gluk Reset Service 6.63 expects bits 0-2 (3 buttons) set to 1 for mouse detect).
    [main.c]
2025-03-19 Makefile: set actual ATmega8 fuses values for AVRDude.
2025-04-05 V.1.1. Add PCB version label. Update README.MD.
    [ZX_BUS_Mouse.kicad_pcb]
2025-06-03 Scorpion ZS 256 Service ROM / ProfROM by @LW_aka_PLM: fixed ROM Disk loading with mouse enabled. Added A15 to IORQGE / ports addresses decode.
    [ZX_BUS_Mouse.kicad_pcb, ZX_BUS_Mouse.kicad_sch]
2025-11-24 V.1.2 gerbers.

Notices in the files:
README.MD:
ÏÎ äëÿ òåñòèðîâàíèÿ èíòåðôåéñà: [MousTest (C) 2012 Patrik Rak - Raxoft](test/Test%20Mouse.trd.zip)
